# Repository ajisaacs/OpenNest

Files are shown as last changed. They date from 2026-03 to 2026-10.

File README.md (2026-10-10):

# OpenNest

A Windows desktop application for CNC nesting — imports DXF drawings, arranges parts on material plates, and exports layouts as DXF or G-code for cutting.

<p>
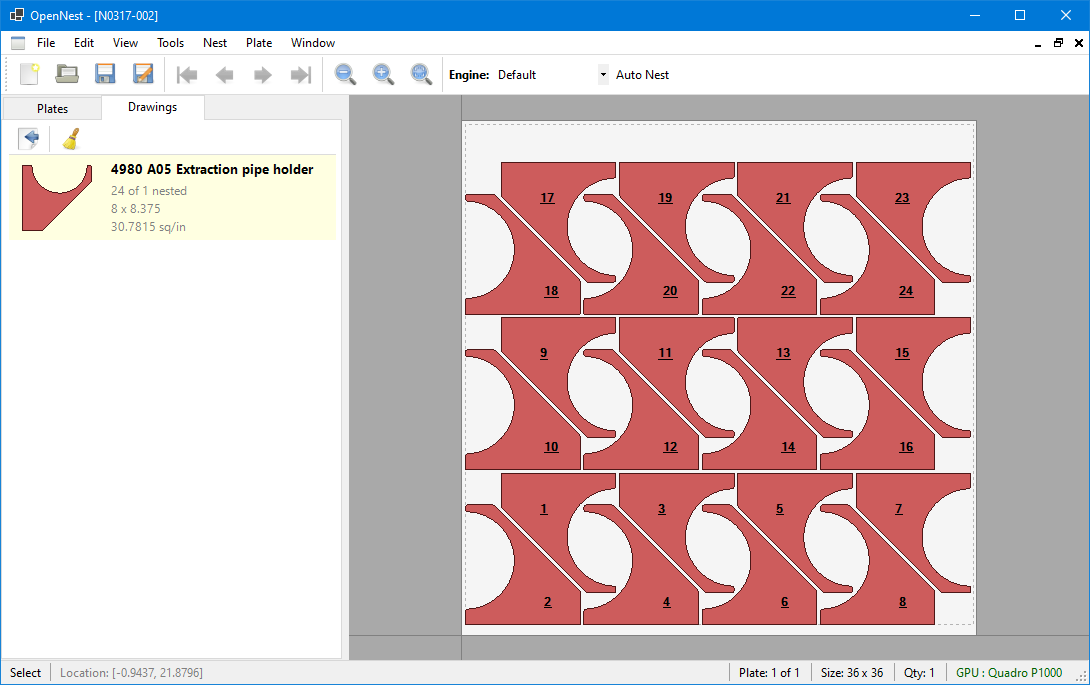
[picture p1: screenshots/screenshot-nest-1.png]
OpenNest - parts nested on a 36x36 plate
  
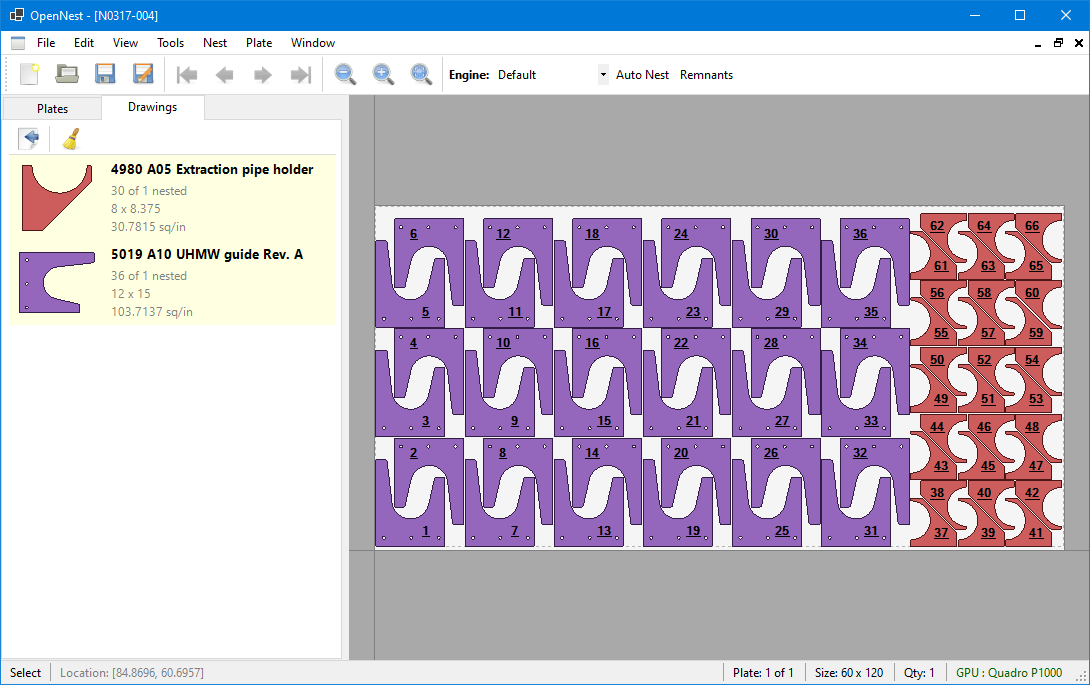
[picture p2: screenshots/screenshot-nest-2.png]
OpenNest - 44 parts nested on a 60x120 plate
  
</p>

## Features

- **Import / export** — DXF & DWG parts (ACadSharp), Excel BOMs, bend-line detection, built-in parametric shapes; export DXF or post-processed G-code.
- **Nesting** — pluggable whole-job engines (Default, Strip, Vertical/Horizontal Remnant, StockLadder, plus DLL plugins), NFP-based interlocking pair evaluation, gravity compaction, rotation sweeps, multi-plate/multi-material jobs.
- **Plate operations** — manual sheet cut-offs, [plate- or nest-wide automatic scrap cutoffs with a minimum tail-to-keep setting](docs/automatic-scrap-cutoffs.md), oversized-part splitting (straight, weld-gap tabs, spike-groove), interactive editing, and spacing-aware pushes that can slide along or away from touching parts.
- **Visual overlap check** — highlight shared material on the active plate, rechecked automatically after edits, including containment and cutouts, with area shading, pair centroids, and hover details through View > Overlap Check. [Usage and limitations](docs/geometry/visual-overlap-check.md).
- **CNC output** — configurable lead-ins/outs and tabs, contour editing, user-defined G-code variables (`$name` → `#200+` machine variables), plugin post-processors (Cincinnati CL-707/800/900/940/CLX included). [Pre-post verification](docs/post-verification.md) checks overlaps, missing lead-ins, and rapid crossings, with explicit risk acknowledgment required to bypass warnings.

## Requirements

- Windows 10+ for the desktop app; the console, API, and most test projects build on Linux/macOS too.
- [.NET 8 SDK](https://dotnet.microsoft.com/download/dotnet/8.0) to build from source.

Windows release ZIPs are self-contained: extract the entire archive into a new folder and run `OpenNest.exe`; no separate .NET installation is needed. The Rectangles and Irregular nesting engines are built in; see [nesting engines](docs/nesting-engines.md). Use the ZIP and SHA-256 checksum from [GitHub Releases](https://github.com/ajisaacs/OpenNest/releases), not the source-code archives.

## Build, Test, Run

```bash
git clone https://github.com/ajisaacs/OpenNest.git
cd OpenNest
dotnet build OpenNest.sln                                       # full solution (Windows)
dotnet test OpenNest.Engine.Tests/OpenNest.Engine.Tests.csproj  # cross-platform engine tests
dotnet test OpenNest.Tests/OpenNest.Tests.csproj                # core/engine/IO/API tests
dotnet test OpenNest.FrontEnd.Tests/OpenNest.FrontEnd.Tests.csproj # console/MCP/API integration
dotnet run --project OpenNest/OpenNest.csproj                   # desktop app (Windows)
```

`OpenNest.WinForms.Tests` (desktop-assembly tests) runs on Windows only; CI runs it and `OpenNest.FrontEnd.Tests` on a GitHub-hosted Windows runner for every master push and pull request. Format changed files with `dotnet format OpenNest.sln --include <path>`.

Shared coding-agent guidance lives in [AGENTS.md](AGENTS.md). [CLAUDE.md](CLAUDE.md) imports it for Claude Code compatibility; make shared instruction changes in AGENTS.md, not in duplicate agent-specific copies.

### Quick start

1. File > New Nest
2. Import DXFs via the CAD Converter (layer/color filtering, bend detection, G-code preview) or create built-in shapes
3. Define plate size, material, quadrant, spacing
4. Fill — the engine arranges parts
5. Optionally add cut-off lines, apply Part Sequencing to order crossing cut-offs before their parts, then save `.nest`, export DXF, or post-process to G-code

Review part spacing before cutting, especially for interlocking pairs. See [pair-spacing checks and current limitations](docs/geometry/pair-spacing.md).

## Command-Line Interface

```bash
dotnet run --project OpenNest.Console -- part.dxf --size 60x120               # fill one plate
dotnet run --project OpenNest.Console -- part1.dxf part2.dxf --size 60x120 --autonest
dotnet run --project OpenNest.Console -- project.zip                          # re-fill a nest file
```

Key options: `--size WxL`, `--autonest` (validated single-sheet whole-job nesting), `--allow-invalid` (explicit warning override), `--engine <name>` (jobs engine or fill strategy), `--quantity`, `--spacing`, `--template <nest>`, `--output <path>`, `--check-overlaps`, `--post <name>`, `--no-save`. Run without arguments for the full list.

## Benchmarking Engines

`OpenNest.Benchmark` runs every registered `INestingEngine` against `.nest` files (or a JSON manifest of DXFs + quantities) and scores by salvage-credited sheet area, with a penalty per unplaced part.

```bash
dotnet run --project OpenNest.Benchmark -- ./benchmark-jobs \
  --sheet-sizes 48x96,60x120,72x120 --engines Irregular,Rectangles --csv results.csv
```

Layouts are validated (bounds, spacing, quantity, rotation, stock match); invalid runs place nothing and pay the penalty. `--parallel` (default 3) speeds up scoring but inflates `Time(ms)` — use `--parallel 1` when comparing speed. Pass `--sheet-sizes` for an unbiased run; otherwise only each file's original sizes are offered. `--progress` logs each solve's start, the engine's `NestJobProgress` (plate evaluations throttled to one line per 2 s, every plate commit) and its finish. Custom engines drop in as DLLs implementing `INestingEngine` (public parameterless constructor) in an `Engines/` folder next to the benchmark. Built-in engines and how to change them: [nesting engines](docs/nesting-engines.md).

## Project Structure

| Project | Purpose |
|---|---|
| **OpenNest** | WinForms desktop app |
| **OpenNest.Core** | Domain model, geometry, CNC primitives; [material-overlap diagnostics](docs/geometry/visual-overlap-check.md) |
| **OpenNest.Engine** | Nesting algorithms and whole-job contracts |
| **OpenNest.IO** | DXF/DWG, `.nest`, G-code, BOM I/O; CAD import |
| **OpenNest.Console** | Headless batch nesting |
| **OpenNest.Api / .Data** | Programmatic pipeline; machine & cutting-parameter data |
| **OpenNest.Gpu** | GPU-accelerated pair evaluation (ILGPU) |
| **OpenNest.Benchmark** | Head-to-head engine comparison |
| **OpenNest.Mcp** | MCP server for AI tool integration |
| **Posts/** | Post-processor plugins (Cincinnati CL / CI Fiber lasers, Gravograph IS8000) |
| **\*.Tests** | Cross-platform suites; WinForms tests are Windows-only |

## Nesting Engines

Engines implement `INestingEngine.Solve(NestJob)`. Desktop Auto Nest, console autonest, MCP autonest and the API use one independent validation pipeline for every engine, including plug-ins. Invalid layouts require an explicit decision; malformed output cannot be kept. See [automatic nesting and validation](docs/automatic-nesting.md) for caller behavior and API validation status.

| Engine | Description |
|---|---|
| **Default** | Any job: runs Irregular and Rectangles and keeps the cheapest valid layout |
| **Rectangles** | Plain and near-rectangular plates: maximal-rectangles box packing |
| **Irregular** | Irregular profiles: no-fit-polygon frontier packing |
| **Fill** | Multi-phase: linear fill → pairs → rect best-fit → extents (named Default in earlier releases) |
| **Strip** | Iterative shrink-fill for mixed-drawing layouts |
| **Vertical / Horizontal Remnant** | Optimizes a clean remnant drop on one edge |
| **StockLadder** | Whole-job, stock-constrained baseline with salvage-credit ranking |

Which engine suits which jobs, renamed engine names, and the rules for changing an engine: [nesting engines](docs/nesting-engines.md).

## File Format

`.nest` files are ZIP archives containing drawing programs, metadata, plates, and placements. Saved nests retain each part's lead-ins, lead-outs, tab gaps, and locks, plus the plate's cutting settings. Changing a drawing's geometry removes obsolete cutting paths from its parts; name, quantity, and color edits preserve them. See the [file-format reference](docs/nest-file-format.md) for compatibility and recovery behavior.

## Supported Formats

| Format | Import | Export |
|---|---|---|
| DXF | Yes | Yes |
| DWG | Yes | No |
| Excel BOM | Yes | No |
| G-code | No | Yes (post-processors) |
| `.nest` | Yes | Yes |

Zoom Out, Zoom In, and Zoom to Fit are centered together with the plate navigation buttons in the plate-view header.

## Keyboard Shortcuts

`Ctrl+F` fill area · `F` zoom to fit · `Shift+wheel` / middle-click rotate · `X`/`Y` push · arrows nudge · `Shift+arrow` push.

## Status & License

Actively developed; core workflows run end-to-end from DXF import to G-code. Contributions welcome. MIT licensed — see [LICENSE](LICENSE).

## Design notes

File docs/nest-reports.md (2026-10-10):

# Nest report PDF export

Desktop: **File -> Export Nest Report...** writes `<nest-name>.report.pdf` for the
active nest's whole job through an overwrite-confirming save dialog. The command
is disabled without an open document and during a background database save, and
it refuses to run while whole-job nesting, an open progress window, interactive
fill or a busy plate action holds the nest or any second window sharing it. After
the dialog closes, the target and those conditions are revalidated; the snapshot
is then captured synchronously on the UI thread and only that detached snapshot
reaches the renderer. Export never changes the selected plate, dirty state,
timestamps or quantities, and it never touches post selection, verification or
CNC output. Opening and printing use any normal PDF viewer; the report includes
no printer controls and there are no persisted report settings or templates.

The same two calls back the command and any future integration:

```csharp
var snapshot = NestReportBuilder.Capture(nest, DateTimeOffset.Now);
NestPdfWriter.Write(snapshot, destinationPath);
```

Reporting does not select a post, generate CNC, refresh drawing quantities, change
the selected plate, or certify that a layout passed geometry/pre-post checks.

## Snapshot contract

- IDs (`1`, `2`, ...) are local to the report. Visit non-cutoff placements in plate
  and part order, then append unseen demanded drawings ordered by ordinal name and
  source path. Identity is by reference: distinct same-named drawings stay distinct,
  including placed drawings absent from the name-keyed drawing collection.
- Recount nested quantities from placements times sheet copies exactly once using
  checked wide integers. Include unplaced demand; report shortage and extra
  separately. Cached `Quantity.Nested` is not authoritative.
- Omit trailing empty stock plates from report pages, layout counts and physical
  sheet totals. Keep the live nest and remaining plate numbers unchanged.
- Distinguish distinct layouts from physical sheets. Per-sheet quantities do not
  include copies; total quantities do. Utilization uses net part area divided by
  full sheet area, excluding cutoffs.
- Actual placed programs already contain rotations. Capture their material paths
  with the location applied once. Preserve holes and intentional tab gaps; exclude
  rapid, scribe, lead-in and lead-out paths. Keep Cut and Display contours.
- If any material contour of a part is open, show all its contours without fill.
  Do not close the gap or substitute the drawing's nominal outline. Cutoffs are
  separate strokes with no product ID or quantity.
- Snapshots retain values, not live drawings, parts, CNC programs or mutable
  geometry. Invalid/missing/nonfinite geometry fails with drawing/plate context.

## Layout, pagination and dense-label fallback

An empty/demand-only job, a single plate, or many plates and drawings all
produce one document: a Letter portrait summary followed by one Letter
landscape section per plate, every page carrying a repeated header and
"Page X of Y". Long notes, long drawing names, many drawings and many parts
per sheet paginate naturally: MigraDoc continues the Plates/Parts tables and
each plate's part table across pages with the heading row repeated, and notes
flow as an ordinary paragraph. No row, table or note text is ever dropped or
truncated to fit a page.

Stock sizes read **width x length** in job units. Plate tables use **Quantity**
and **Parts per plate**; the plate quantity multiplies per-plate part counts for
the totals.

Individual IDs use 7 pt text centered on the part's pole of inaccessibility
(`PolyLabel`, as in `PlateView`), clear of edges, holes, cutoffs and other labels.
The search uses a placement-independent quantized copy for consistent placement
on identical parts. Labels are best effort: there are no closeup or grid pages,
and a part too small to label never prevents export. Every part remains in the
quantity tables even when its diagram label cannot fit.

Nearby small parts with the same report ID may share a dotted rectangular outline
and one ID beside it. Separate clusters get separate outlines. A group is omitted
if its rectangle includes any other part or cutoff, or if there is no clear space
for its label. Dotted group outlines are distinct from dashed scrap cutoffs.

The writer still rejects, with `NotSupportedException` and before touching
the destination:

- a page header (nest name plus plate/material line) needing more than 3
  wrapped lines;
- a table cell needing more than 20 wrapped lines.

Summary thumbnails and the sheet diagram are vector paths, never raster images.
Each thumbnail is a small PDFsharp page embedded by MigraDoc as a form XObject.
The diagram is drawn into a fixed-height table row reserved in MigraDoc's flow,
located after layout with `DocumentRenderer.GetRenderInfoFromPage`. Closed parts
use one even-odd filled path, so holes stay unfilled. Parts with any open contour,
and cutoffs (dashed), stroke each contour as its own path: PDFsharp's
`StartFigure` does not start a new subpath after an open figure, and would
otherwise draw a false segment across a tab gap.

A report is fully rendered to a unique temporary sibling before replacement of
its destination. A failed render or write leaves an existing report untouched and
removes temporary output. Applications should obtain overwrite consent before
calling the library. PDFsharp/MigraDoc layout and font state is process-wide;
`NestPdfWriter.Write` serializes every export behind one static lock so
concurrent calls cannot lay out text differently from a sequential export.

Advanced timing, cutting distances, pierce counts, weights, costs, gas use, and
machine/NC identity are intentionally omitted until their semantics are verified.
The PDF can be opened or printed through a normal PDF viewer; its fitted diagram
is not a dimensioned cutting drawing.

## Backend, fonts and redistribution

- Official `PDFsharp-MigraDoc` Core **6.2.4**, with `PDFsharp` **6.2.4**, targeting
  net8.0. No GDI/WPF dependency or printer driver is used. MigraDoc owns flowing
  document layout; PDFsharp draws vectors into its measured reserved areas.
- DejaVu Sans **2.37**, regular and bold, is bundled unmodified as assembly
  resources. Source: https://dejavu-fonts.github.io/ ; binary provenance:
  Ubuntu `fonts-dejavu-core` **2.37-8**. Both required faces are embedded in PDFs;
  neither generation nor viewing needs a platform font installation.
- A custom resolver is installed once before fonts are created. Repeated exports
  reuse it. An already-installed foreign resolver is an explicit integration
  error, never silently replaced. A host that already uses PDFsharp needs resolver
  composition before adding report support. MigraDoc's predefined error font is
  pointed at the bundled family; its default (`Courier New`) is a platform font
  the bundled resolver deliberately cannot supply.
- The initial text contract is printable ASCII/Latin-1 and line/tab separators.
  Other codepoints, controls and soft hyphens fail with the field and codepoint;
  there is no silent missing-glyph substitution. Broader Unicode/shaping support
  is deferred rather than implied by the font's larger character inventory.
- PDFsharp/MigraDoc are MIT-licensed. The actual v6.2.4 license and the Microsoft
  transitive dependency notices are in `OpenNest.Reporting/THIRD-PARTY-NOTICES.txt`.
  Font permission/redistribution terms are in `OpenNest.Reporting/Fonts/LICENSE.txt`
  (Bitstream Vera permission with DejaVu changes in the public domain). Preserve
  both files in `ReportingNotices/` when publishing; embedded fonts do not replace
  the obligation to ship their notices. Package notices are deduplicated, not
  rewritten or shortened.

## Verification

```sh
dotnet test OpenNest.Tests/OpenNest.Tests.csproj --filter FullyQualifiedName~Reporting
```

The writer tests read page sizes and content streams with PDFsharp. Text
assertions use Poppler's `pdftotext -bbox` coordinates to rebuild visual rows;
`-layout` can return columns in a different order on Windows. They are skipped,
not passed, when poppler-utils is absent. The Windows release workflow installs
an SHA-256-pinned Poppler binary because the runner's built-in `pdftotext` lacks
`-bbox`; no PDF text test is skipped for that reason in a release candidate.
For manual inspection also use `pdfinfo`,
`pdffonts` and `pdftoppm -png` (Linux verification baseline: poppler-utils
24.02.0). Confirm page sizes, quantity rows, page X of Y, embedded fonts, native
vector curves, unfilled holes and visible tab gaps with no connecting stroke.
Pixel inspection supplements geometry assertions; it is not a CNC-validation
result.

Windows compilation is not runtime acceptance. `OpenNest.WinForms.Tests/Forms/NestReportExportTests.cs`
covers enablement, busy/cancel/failure/success adapter behavior, but it only
compiles on Linux. Windows runtime acceptance still owes: exporting a real nest
(and the packaged application, so bundled fonts/notices are verified), checking
page sizes/labels/copies and embedded fonts with `pdffonts`, a tabbed part with a
hole, opening and printing the PDF, and exercising fill/nesting rejection, cancel,
overwrite and invalid-path behavior with job state and any existing destination
unchanged.

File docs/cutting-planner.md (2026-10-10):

# Unified cutting planner: direct-XY proposals

`OpenNest.Engine.CuttingPlanning.CuttingPlanService` plans contiguous whole-part
programs. It can retain fixed programs or jointly choose internal contour order,
entries and whole-part order using explicitly confirmed cutting parameters. It
returns an owned proposal; `Apply` installs Ready plate-scoped proposals atomically
after an exact freshness check. The desktop opens it from `Plate > Plan Cutting...` and
`Nest > Plan Cutting (All Plates)...` (see [Desktop workflow](#desktop-workflow)); the older
automatic sequencing and lead-in assignment commands remain until they are retired.

## Capture before worker planning

Create a `CuttingPlanRequest`, then call `Capture` while source placements,
programs and settings are stable. Pass that snapshot to `Plan` on a worker;
`Plan(request)` combines these steps synchronously. The modeled starting point
defaults to `Vector.Zero`, not a discovered controller position.

```csharp
var request = CuttingPlanRequest.ForPlate(plate, startPoint: start,
    confirmedParameters: parameters, expansionBudget: 20000,
    maxEntries: 16, preservePartOrder: false);
var snapshot = CuttingPlanService.Capture(request, cancellationToken);
var result = CuttingPlanService.Plan(snapshot, cancellationToken);
```

- A plate-scoped request (`CuttingPlanRequest.ForPlate`) plans the plate's current
  parts and records its exact state for `Apply`. A detached part list (`new CuttingPlanRequest(parts, ...)`)
  plans the same way but can never be applied. An empty plate is a Ready no-op.
- Omitting `confirmedParameters` preserves the original fixed-program contract:
  locked and unlocked programs stay fixed; only whole-part order may change.
- Supplying confirmed parameters enables regeneration for unlocked placements.
  `eligibleParts` can restrict it to an explicit reference-based subset; an empty
  subset retains all programs but still checks their leads against owned material.
  Locked placements never regenerate. Foreign or duplicate eligible identities
  are invalid; eligibility without confirmed parameters is invalid.
- `preservePartOrder` fixes whole-part order, not eligible internal contour choices.
- Parameters are caller-confirmed inputs. The service does not recover missing
  operator settings or silently change lead styles to find a solution.

Capture owns clean geometry, placed programs and required settings. Source `Part`
references are identity handles only: workers never read their mutable state.
Clean geometry accounts for the base program's existing rotation before applying
placement rotation; placement translation is applied once. Subprogram copying
must not rotate shared programs through their property setters. No live drawings
are attached to preview plates, so capture/search do not change quantity accounting.
Planning works from this historical snapshot; Apply compares it with live state.
Original
clean and executable graphs are type/mode-checked before cloning can erase unknown
semantics. Exact placed/proposed copies preserve authored motion feed/exact-stop
flags, symbolic bindings and shared subprogram identity; unsupported graphs are
refused. The geometry-only clean transform uses per-parent copies so legacy rotation
does not visit a globally shared descendant twice; it never changes the fixed payload.

## Cutting dependencies

Nominal material validation recognizes contacts at shared endpoints of adjacent
contour segments using `OpenNest.Math.Tolerance.Epsilon` (0.00001 model units).
This avoids false self-intersection warnings from rounding at arc/line joints,
including the contour seam. Overlapping segments and contacts away from those
joints or between separate contours still fail validation. For adjacent finite arcs
with a shared endpoint, material validation filters native contacts against both
actual arc spans: the native query's angular padding can otherwise report a
supporting-circle intersection beyond one arc's endpoint. This does not increase
the joint-distance tolerance, discard overlapping arcs, or waive a second intersection
inside both spans. Lead and rapid checks keep their conservative contact queries.
Source contour closure
in material capture and emitter preparation accepts endpoint gaps up to 0.000001
model units (inches for an inch nest), with a floating-point roundoff allowance
capped at 1e-12. It does not rewrite source endpoints. Native intersections,
executed-motion checks and pre-post verification retain their existing tolerances.

Capture builds whole-part prerequisites from owned values, and both the search and
the final replay enforce them:

- A cutoff precedes every part its nominal line crosses within its span, using the
  same rule as automatic sequencing: nominal position and limits against the part's
  placed bounds, matched by drawing reference, never by name or trimmed segments. A
  cutoff whose definition is missing precedes every part. Cutoffs need a
  plate-scoped request; they are always fixed programs, need no lead-in, are not
  material for lead validation and, being open cuts, never become rapid obstacles.
  Rapids into and out of them are still checked.
- A part whose perimeter lies strictly inside a cutout of another part precedes
  that host. Material bounds (never rapids or scribe marks) only select candidate
  pairs; containment is proven on native clean material. Touching or crossing boundaries, or material that cannot be
  captured, refuse as `UnsupportedGeometry` naming both parts. A part in a concave
  pocket outside the host's material has no dependency.
- A preserved manual order that violates a prerequisite, or a cycle, is a
  `ConstraintConflict`. Replay rechecks the captured prerequisites and refuses a
  violating order rather than trusting the search.

## Search and exact output

With regeneration, the bounded deterministic search plans internal contour order
and native entry candidates part by part along a whole-part order. Internal
contours precede their own perimeter; parts remain contiguous. Backtracking can
revisit an earlier entry when a later part cannot be reached safely. For multi-part
requests containing regenerated holes, it first tries one ranked hole chain for
each outside endpoint. This lets a later blocked approach change the previous
part's departure without first exhausting combinations of its earlier holes.
This preferred pass uses the same emitted-motion checks, shared expansion budget
and stall limit as the retained search; on failure the full entry/hole-order
backtracking pass remains available. Single-part and no-hole requests keep their
existing search order.

A preserved order is followed as given. Otherwise the order is an open
travelling-salesman path over part centres from the start point: nearest neighbour,
then 2-opt reversals and Or-opt moves of one to three parts, never placing a part
before a cutoff or nested-part prerequisite. If a part on that order cannot be
reached without crossing parts already cut, the search learns "cut this part
before those", backs up to just before the earliest of them and re-plans the rest
from the tool position there; parts cut before that point are kept. An attempt
stops backtracking after a stall of 8 x entries x contours expansions without
getting further, so it learns instead of retrying every entry combination of the
parts before it. A rule that would contradict an order already required is skipped.
"Cut before" rules are a heuristic (a part blocked straight after another may be
reachable via a third), so once nothing new can be learned the remaining budget
goes to a full search that tries every ready part, nearest first; only when that
also fails is the result a refusal.

Candidates use native closest points, vertices, midpoints and circle angles in
stable order, capped by `maxEntries`. Circle rounding, clamping, corner resolution
and tab trimming happen during emission. Validation uses the actual emitted
motions, never the nominal entry point alone. Existing lead styles are not
shortened, disabled or substituted as a search fallback.

Whole-circle candidates rank by distance to their next-cut target; for a hole,
that is the next contour's actual pierce. They do not reward a diagonal point as
if it were a bounding-box corner. All eight
compass options remain available, including the four polar points at 0°, 90°,
180° and 270°, and every alternative still passes the emitted-lead and rapid checks.
Without a next-cut target, the arrival-based rule is unchanged. Polygon corner
preferences are unchanged.

`Round Lead-In Angles` remains an explicit cutting setting: a 90° increment snaps
circular-hole starts to the four polar directions; 45° also permits diagonals.
Snapping can increase reuse of identical hole subprograms and reduce output for
posts that support that reuse, at the cost of a less direct departure. It is not
a clearance exemption or a guaranteed file-size reduction. The planner does not
silently enable rounding, change the increment, or bypass checks on the rounded
motions.

Every candidate rapid is checked against contours already completed, including
earlier holes in the same part. Future contours are not yet obstacles. Rapid
checks skip completed contours whose extents are more than 0.001 clear of the
rapid, ten times the widest band any native contact query allows beyond an
extent; anything closer, touching included, gets the full native check. Lead
checks examine every other part's material: native line/circle queries can report
rounding contacts for long leads far from small circles, and leads keep those
results. An arc's
extent is its whole supporting circle widened to the distance at which the native
contact query still counts it as touched (for a very small arc up to 0.0001 beyond
its radius). Nothing is skipped when either extent has a nonfinite bound or reaches
beyond 1e6, where rounding of large supports can exceed any fixed margin. Actual
lead-in and lead-out line/arc paths must stay in target scrap and avoid other
placed material; holes in other parts remain scrap. Tangent/coincident contacts
outside the genuine target contour joint and numerically uncertain queries refuse.
Material capture supports a simple closed perimeter minus disjoint, non-nested
holes; unsupported topology is not a bounding-box approximation. A line meeting a
tangent arc at a shared vertex, such as a fillet, is an ordinary joint: an exact
contact that the native query rounds away is not uncertain at a line endpoint the
other curve already touches, while a contact anywhere else on the line still refuses.

Source parts rank by modeled travel (material-centre distance at a holed-part
boundary); within a part, preferred contour order and facing-entry rank precede
travel. Ties use stable source/contour/entry ordinals. Hash values and drawing names
are not tie breakers.

When the next whole part is fixed by the tour or a part is already active, the
search generates and checks contour alternatives on demand in contour/entry rank
order. It does not emit every sibling before trying the first. Backtracking still
visits the remaining alternatives when needed; none is pruned. The free whole-part
fallback still evaluates all ready sources before ranking their travel distances.

The expansion budget counts evaluated candidates and frontier ranking, including
rejections, before emission; it is not a wall-clock timeout. An unvisited sibling
consumes no additional DFS-prefix emission work or per-sibling expansion charge;
entry-catalogue prechecks still emit isolated contours and consume budget.
Consequently a bounded search can
reach a different frontier and report different rejected approaches than eager
expansion did. All visited candidates retain their lead/rapid checks, and a selected
plan still receives fresh independent replay. Callers can cancel. Exhaustion returns
a refusal, not an unranked fallback or proof of geometric impossibility.

## Automatic outside entries and look-ahead

An unlocked part's outside entry is chosen automatically toward the NEXT cut: the ranker orders the native candidate
catalogue by the facing side(s) of the next part's placed-material centre, and
the shared lead validator certifies each emitted lead lazily until up to
`maxEntries` feasible candidates remain. At caps of four or more, a corrective
scan reconsiders memoized clear candidates for each missing side before evaluating
more of the catalogue; a later side cannot lose a usable point merely because
an earlier side's scan passed it. Replacements preserve other covered sides and
global rank, never exceed the cap, and stop evaluating the tail once coverage
settles. Smaller caps retain rank priority rather than promising all-side coverage.
The next cut is the next unfinished part in a supplied order — recomputed
after every learned-order replan — or, in the full fallback search, the nearest
dependency-ready remaining part, stable-ordinal ties; the last part has no
target and ranks by tier then distance to the tool's arrival. Between source
parts the tour stays nearest-first; the look-ahead rank only orders the entries
inside one part's contour stage, so distance sorting cannot undo the facing.
Uncertain (numerically incomplete) validator answers are not geometric refusals:
those candidates can fill remaining retained slots for emitted-prefix checking and
complete replay. The total retained entry count stays within `maxEntries`. A
part/contour with no fitting lead in its fully evaluated catalogue is reported
as "No tested lead-in fits on part N, contour M"; budget exhaustion stays a
budget finding and incomplete checks are never presented as geometric
impossibility. Lead prechecks are reported separately and their requests also consume
the shared expansion budget before native work.

For a holed part, the search chooses an outside endpoint before cutting any hole.
Each endpoint branch builds an open hole-centre route from the original arrival to
that endpoint, using bounded nearest-neighbour, 2-opt and Or-opt improvement.
Preferred hole entries are then resolved backward from the outside's actual emitted
pierce, ignoring scribe marks: each hole faces the following contour's actual pierce.
Convex corners lead the preference tiers, then straight midpoints/tangent joints,
then native fallbacks. Reflex/cusp corners remain manual-only.

This preference orders the search; it never certifies a rapid or prunes alternate
retained entries or hole orders. A different outside endpoint recomputes its hole
preference. Every standalone emitted prefix is replayed from the original part
arrival and a copy of the checker from before that part, not from the previous
prefix (which would double-consume holes and scribes). Holes are cut once, the
outside last, and scribes once. Locked programs remain exact. A crossed preferred
route must recover through checked backtracking or return a refusal, never unsafe
`Ready`.

Selected programs are replayed from the beginning with a fresh checker and fresh
lead validation, without regenerating them or trusting cached search verdicts.
Before replay, expected-emission geometry is independently built from the owned
choices/settings, not from the candidate payload. Replay checks actual selected
code against it and independently accounts for directed native boundary coverage:
no partial, duplicated, retraced or reversed cuts, except the exact selected tab.
Equivalent subdivisions and merged collinear moves remain valid. Captured source
identity and pose binding use exact scalar bits, not geometric tolerance.
Arrival positions use actual departures, including lead-outs and subprograms.
`ProposedOrder` retains source identities/poses; `CopyProgram()` returns an
independent deep copy of each exact captured/generated program. `ContourChoices`
are nominal choice metadata, not a substitute for reading actual execution.
Neither obtaining a proposal nor copying its programs installs them on live parts.

## Results and refusal

`Ready` and `IndependentlyReplayed` describe the modeled proposal only. In the
no-parameter fixed route, replay checks rapid crossings and
incomplete retention; it does not add regeneration-mode material/lead checks.
In regeneration mode, replay also checks actual lead paths and contour accounting
against owned clean material. Neither mode certifies final NC, production cutting
readiness or physical machine safety.

Findings and source ordinals use the original zero-based source list, not proposed
sequence positions. Strict service refusals contain no proposed order. The desktop batch may
produce a separate `BestEffort` proposal as described below; it never labels it `Ready` or
sets `IndependentlyReplayed`.

- `ConstraintConflict`: fixed programs or explored fixed routing violate the
  modeled constraints. Locked internal crossings cannot be repaired by regeneration.
- `UnsupportedGeometry`: unsupported motion/material semantics or an incomplete
  check. Open nominal outlines, ambiguous release states or containment, cutoffs
  in a detached part list and scribe-only source drawings are not silently accepted.
- `InvalidInput`: malformed/missing/duplicate placements or settings, invalid
  geometry, empty input, invalid eligibility or nonpositive bounds.
- `NoSolutionWithinBudget`: the bounded/capped search found no complete proposal;
  it does not prove no possible geometric route exists.
- `Cancelled`: capture, search or replay cancelled without live mutation.

Malformed original executed graphs are refused, not salvaged. Valid but incomplete
old programs can regenerate from clean geometry. Regenerated programs retain genuine
configured tab gaps; stale tab settings do not establish retention. In confirmed-
parameters mode, locked/ineligible programs must cover the complete directed clean
boundary: an open fixed program has no certified selected tab metadata and is refused,
not repaired, even if it may have been intentionally tabbed. The no-parameter route
retains its narrower compatibility contract. A lead-out that may bridge a tab, or
a malformed emitted arc, is refused, not automatically repaired. Tabbed lead-outs
leave from the trimmed cut end, but a lead-out after an open contour still needs
manual review of its retention gap, so confirmed-parameters planning refuses it.

## Apply

```csharp
var commit = CuttingPlanService.Apply(results, cancellationToken); // one result per plate
```

Call it on the thread that owns the plates, with Ready, independently replayed
results from plate-scoped requests; anything else is `InvalidInput`. Apply never
replans. Each plate is compared exactly with the state captured with its request:
part list instance and order, plate quantity/size/quadrant and settings, cutoff
definitions, and for every part its program reference and exact content (an
in-place edit counts), drawing program and cutoff classification, pose bits,
lead-in/lock flags, settings (reference and exact content) and bounds. Any
difference on any plate returns `Stale` and changes nothing, so a proposal that
changes a plate can be applied once; an unchanged (no-op) proposal stays current.
A malformed live program is also `Stale`, not an exception. A part repeated on
two plates of one scope is `InvalidInput`. Caller-confirmed planning settings are
input, not plate state: editing a separate confirmed-settings object after
capture does not stale the result (confirmed settings that are also a part's or
the plate's live settings are live state, and editing them does). Settings are
compared member by member, and only the exact built-in settings types are
supported (the same set regeneration copies): a plate-scoped request whose part
or plate settings, or any lead-in, lead-out, tab, sequencing or assignment
object inside them, is another type (a subclass included) returns
`UnsupportedGeometry` without running that type's code. A settings object
replaced by such a type after capture makes `Apply` return `Stale`. Detached
part-list requests do not capture settings and are unaffected.

The whole scope is validated and its bounds staged first; cancellation is checked
immediately before the install. Order changes through `ObservableList.Reorder`
semantics: same references, no `PartAdded`/`PartRemoved`, so drawing quantities,
sentinel plates and plate lists are untouched. Regenerated parts receive a fresh
owned copy of the replayed program and of the settings captured with the request,
keep their pose and lock, and are marked as having lead-ins. Fixed programs are
not replaced. An exception during install restores every plate exactly and returns
`Failed`. The installer itself is internal: it trusts these owned payloads and
checks only root program references, so `CuttingPlanService.Apply` is the only
public path. After the whole scope is installed, each changed plate raises
`Plate.PartsReordered` once; an observer exception is reported in `RefreshErrors`
on an `Applied` result, not as a rollback.

## Desktop workflow

`Plate > Plan Cutting...` plans the active plate and `Nest > Plan Cutting (All Plates)...`
plans every plate that has parts. Both open one dialog built on
`OpenNest.Engine.CuttingPlanning.CuttingPlanBatch`:

- The dialog starts from the plate's cutting settings (or the last-used settings) and plans
  at once. `Cutting Settings...` edits them and `Keep the current part order` fixes the
  whole-part order; either change replans. The settings are confirmed parameters: every
  unlocked part's lead-ins are regenerated. Locked parts keep their exact programs;
  the strict route checks them, while any best-effort warnings require explicit review below.
- Lead-ins are optional for planning. With `None` (or a style that emits no lead
  motion), the emitter places the pierce directly on the selected contour point.
  Unlocked contour starts can still move to improve travel; locked programs keep
  their existing starts. Search and independent replay still check rapid crossings,
  emitted lead paths when present, and contour accounting. The separate pre-post
  missing-lead warning remains available for operator review; a ready plan does not
  waive posting checks.
  When a lead hits another part, the finding suggests more spacing or a shorter lead;
  when no tested entry fits, it suggests reducing lead-in length and, if neighbours
  obstruct it, spacing the parts farther apart. These are suggestions, not guaranteed
  fixes: replanning runs the same strict checks; an unverified fallback requires
  separate warning acceptance and is not approval to post or cut.
- The desktop free-order batch first tries up to eight entries per contour for at most
  1,000 expansions. Only a Ready proposal that passes independent replay is used;
  otherwise it runs the original 16-entry search with its entire plate budget.
  Cancellation stops both attempts. This short pass can choose a different valid
  route, and a hard plate can take up to 1,000 extra expansions before the full
  attempt. The current-order retry still uses its original 16-entry budget.
  Returned expansion counts describe the retained attempt, not a discarded
  short pass plus its full-cap retry.
- Every plate is captured on the UI thread and checked and planned on a worker. Clean part
  material is checked for overlaps with the pre-post overlap analyzer; known overlapping parts
  still block that plate whatever its route. Incomplete checks remain visible warnings, never
  a clear result (see [pre-post verification](post-verification.md)). A free-order search that ends
  `NoSolutionWithinBudget` is retried once with the current part order, and the summary
  says the order was kept. Both are allowed 400 expansions per part (at least the
  default 20000), because both still plan contour order and entries for every part.
- The dialog uses an owner-monitor-sized window (approximately 90% of the working area), like
  the database browser. The right panel keeps the batch outcome and plate headings above a
  read-only, unsorted warning grid with Plate, source Part, With, and full finding text. Every
  overlap issue/pair and every planner finding has its own selectable row, including findings
  hidden by the compact blocked-plate summary. Selecting a row switches to that plate's
  detached preview and zooms to the affected part extent (or both parts for a pair), mapping
  source positions to the proposed cutting order. This is not an exact contact marker: most
  findings do not carry a geometric witness. If a plate cannot produce a current, supported
  preview, no geometry is cloned or focused; the row still identifies its source part in the
  editor. Replanning, cancellation and stale Apply clear old warning targets.
- The summary lists every plate: ready plates with part counts and rapid travel, others
  with their status and findings. Unverified proposals retain every overlap and route
  warning in the selectable grid before the acceptance checkbox is used; they do
  not truncate later parts' warnings. Finding part numbers are the plate's current order, as the
  editor numbers them. The preview shows the active plate detached from the nest (quantity
  zero, so drawing quantities do not change) in the proposed order with the proposed
  programs. Ready and best-effort proposals can be previewed only while the plate still
  matches capture. Best-effort previews are labelled `UNVERIFIED`. Refused program graphs
  are never copied, and changed plates require replanning.
- Apply requires usable output for every plate and remains all or nothing. The summary
  counts best-effort proposals as usable when reporting how many plates block Apply;
  their warnings still require acceptance. Open nominal contour findings identify the
  contour number, endpoint gap in model units (the nest's linear units), and closure
  tolerance, so the source can be reviewed in the drawing editor. Reporting never
  closes gaps or changes the validation tolerance. A fully ready batch
  can apply immediately; an unverified batch requires the unchecked, per-proposal
  `I reviewed the warnings. Apply this unverified plan.` checkbox. Replanning clears it.
  Both use the same owned-program, freshness and rollback boundary. After it applies, each plate keeps its own copy of the
  confirmed settings, which also become the saved defaults. `Stale` keeps the dialog open
  and asks for a replan; nothing changes.
- Closing or cancelling while planning cancels the worker and keeps the dialog open until
  it stops. Planning and Apply refuse to start while a nesting or plate operation runs.
  The dialog plans with its own copy of the settings, and posts progress and results to
  the thread it was created on rather than to whichever context is current.
- `PlateView` follows `Plate.PartsReordered`: it redraws parts in the plate's order (the
  numbers it draws are the cutting order), rebuilds their graphics and marks the overlap
  check out of date. Both the editor and preview build outlines and lead paths in the
  drawing-local frame, then apply the part placement once. Absolute (G90) programs
  therefore follow moves and clones just like incremental (G91) programs; displaying a
  part does not rewrite its program or coordinate mode.

### Best-effort fallback for imperfect geometry

When strict planning reports unsupported or incomplete geometry, the desktop batch
automatically attempts a bounded, deterministic best-effort proposal. Touching, intersecting
or numerically uncertain material boundaries need not prevent lead-in generation when their
closed executable contours are readable. The fallback reuses the existing contour emitter:
internal contours first, the largest bounding perimeter last, nearest entry from the preceding
departure, with the confirmed lead styles. It retains source part order except to satisfy
proven cutoff and nested-part prerequisites. `Keep the current part order` still refuses an
order that contradicts a proven prerequisite. Uncertain containment is named as a warning.

No source contours are repaired, removed, simplified, or silently closed. Locked programs
and cutoffs remain exact. Unknown/null/recursive instruction graphs, suppressed or nonfinite
motions and contours the emitter cannot represent still refuse. This fallback is for
incomplete geometry checks, not every constraint conflict or exhausted search. Known
inter-part material overlap still blocks the entire batch.

The result retains strict refusal findings and available rapid-check findings, and is
explicitly not a certificate of lead clearance, rapid travel or material containment.
Inspect the preview and warnings before accepting it. A route with only an incomplete
overlap check may likewise be accepted with warnings. `CanApply` and parameterless batch
`Apply()` remain strict; `CanApplyWithWarnings` and `Apply(acceptWarnings: true)` are the
explicit review path. `CuttingPlanService.Apply` still rejects best-effort results directly.
Acceptance never skips the separate pre-post checks or grants posting consent.

## Remaining integration boundaries

The service does not establish clean-material non-overlap, scrap release by open
cutoff cuts or sheet edges, or physical retention strength. It does not write CNC
or set posting consent. A `Ready` proposal can still be unsuitable for cutting.

Later slices route the lead-in side panel's automatic assignment through the planner
and retire the legacy automatic paths. Windows interaction,
supplied-job coverage and actual posted order remain separate acceptance gates.
Fresh [pre-post verification](post-verification.md) is still required; it is not a
physical safety qualification.

## Portable regression gate

```sh
dotnet test OpenNest.Tests/OpenNest.Tests.csproj -c Release --filter 'FullyQualifiedName~CuttingPlanning|FullyQualifiedName~PostVerificationAnalyzerTests'
```

Synthetic fixtures exercise whole-part routing and internal-hole crossing repair,
locked/ineligible refusal, actual native lead paths, shared subprograms, ownership,
entry/whole-part backtracking, deterministic budgets, cancellation and fresh replay
rejection. Retained emission characterizations cover styles, winding, corner rules,
circle rounding/clamping and tabs; unsupported cases remain explicit refusals.

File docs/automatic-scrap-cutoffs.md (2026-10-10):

# Automatic scrap cutoffs

Finish nesting, then choose **Nest > Automatic Scrap Cutoffs (All Plates)** to process the entire nest with one dialog. **Plate > Automatic Scrap Cutoffs** still processes only the active plate. The manual **Sheet Cut-Off** command remains available.

## Preview and apply

1. Finish or cancel any active nesting/fill operation first, and wait for it to finish stopping; closing its progress window alone does not finish the operation. Enter strip spacing along the sheet's length. The initial value is **35 in**, or **889 mm** for a metric nest. This is the distance between nominal cut lines, not the length of a cut.
2. Set **Minimum tail to keep**, initially **12 in** or **304.8 mm**. This measures the reusable tail's length along X, after separator clearance, not its area. A shorter tail does not get a new final separator; a tail at or above the minimum can be retained. Zero allows any positive tail.
3. Opening the modal dialog previews the initial proposal. After changing either setting, choose **Preview** to refresh it. Cuts run across the active sheet's actual width, advancing along X from the origin-side edge in the plate's quadrant. Review the used span, proposed separator, retained tail dimensions, and diagnostics; the sheet cannot be edited while the dialog is open.
4. Choose **Apply** (or **Apply to All Plates**) to recalculate against the current parts/settings and add ordinary cutoff definitions at the end of each plate's cutting sequence. Blocked or empty proposals add nothing. Existing parts and manual cutoff definitions are not moved or reordered. **Cancel**, Escape, and closing the dialog discard the detached preview.

For the Nest command, the on-sheet overlay and upper measurements show the active plate; the scrollable diagnostics list reports every plate's proposed cuts, occupied/used spans, retained tail and warnings. Each plate uses its own dimensions, quadrant and part spacing with the dialog's common spacing/minimum-tail settings and current cutoff clearance/direction settings. No plate navigation or per-plate confirmation is required. Empty or unchanged plates are left untouched. A blocking conflict or invalid plate prevents changes to **all** plates, with the plate number reported; resolve it before retrying. If application fails after changes begin, all touched plates' original cutoff programs and sequence are restored. An explicit incomplete-recovery warning requires manual review before saving or cutting.

An empty sheet is left untouched. Invalid input or out-of-sheet part geometry prevents automatic planning. Excessively small spacing is rejected rather than allocating an unbounded number of cuts. Ordinary floating-point roundoff between translated material and cached bounds is accepted without changing the part or its program; cutoff obstacle checks and fallback exclusions receive the same conservative numerical padding. Larger discrepancies (for example, an inconsistent arc center corrected during conversion) still prevent planning rather than risking a cut through material; repair the geometry before retrying.

## Preserving the unused tail

A proposed tail shorter than **Minimum tail to keep** is left attached to the scrap skeleton by omitting only the final separator. The nominal skeleton grid is not extended into that tail, and no retained tail is claimed. Existing cutoff definitions—including an end cutoff from an earlier run—are never removed by this setting.

Only real parts contribute to the occupied envelope; existing cutoff parts do not. When there is room, the final separator is beyond the furthest occupied extent by the larger of plate part spacing and cutoff part clearance, plus numerical tolerance. Repeated skeleton cuts stop before that separator. The larger margin affects only the separator: repeated cuts keep the existing manual-cutoff clearance behavior.

Cutoff trimming measures clearance from the part contour, excluding tagged lead-in and lead-out moves when building the closed outline. Leads must not turn a recessed outline into a convex hull and leave oversized gaps elsewhere. Genuinely open contours still use the conservative hull/bounds fallback. The conservative curve/offset approximation can leave a small extra gap (about 0.0003 in on a straight edge at the default 0.02-in clearance), not an extra quarter inch.

If no safe separator fits inside the sheet, there is no retained-tail claim and the nominal cuts may cover the full sheet length. A proposed tail is not reported as separated unless its generated program spans the full sheet width. Obstructed or minimum-length-filtered lines produce diagnostics; they are not proof of a completed partition.

For a 120-by-81-inch sheet whose parts extend through 80 inches, the nominal skeleton lines are at 35 and 70 inches, followed by a separator beyond 80 inches at the required margin. There is no line at 105 inches through the retained tail.

## Limits and operator review

**View > Draw Rapids** follows the complete cutting sequence: an incoming rapid ends at a cutoff's first pierce, gaps between its trimmed segments remain rapids, and the next part's rapid starts at the cutoff's final cutting endpoint—not its last pierce. This display does not add a return move or alter the cutoff program.

- Spacing is nominal. Clearance gaps and suppressed short segments can leave bridges between scrap regions. This command does **not** certify that every connected scrap piece is disconnected or fits a hopper.
- The active sheet's physical width is used, not a hard-coded 81 inches. Check the actual width against the hopper; a wider sheet is not automatically hopper-compatible.
- Internal-hole scrap is not processed. This command reuses the outside-skeleton behavior of manual cutoffs; it does not force cuts through parts or remove clearance to guarantee separation.
- Review the preview and posted NC using the normal machine-review process before production cutting.

## Part sequencing

For **Plate > Sequence Parts > Manual Sequence**, choose the one-based sequence number and hover a part on the sheet; only the part under the pointer is outlined. Click it to place it at that exact position, then the number advances up to the last part. Clicking empty sheet space changes nothing. Use **Done**, the window close button, right-click on the sheet, or Escape to leave the tool. Manual reordering changes neither geometry nor quantities.

After adding cutoffs, apply **Part Sequencing** to the current plate or all plates. Each cutoff is moved earlier as needed so it is cut before every part its nominal line passes through. Ordinary parts retain their relative order from the chosen sequencing route; a tail separator that crosses no parts keeps its normal route position rather than being forced to the front. Cutoff geometry, clearance, part programs, placements, and quantities are unchanged.

The dependency check uses the nominal horizontal/vertical line and its start/end limits, not the trimmed cutting segments, which intentionally skip the parts. It conservatively checks placed part bounds (including edge contacts), so a cutoff through a concave recess can also move ahead of that part. Definitions are matched by drawing identity, not their displayed names. A cutoff part with no matching definition is conservatively ordered before all ordinary parts.

This rule runs when applying automatic sequencing, after reversing the exit-first sequencer route into cutting order. Manual sequence edits are still manual; adding or moving cutoffs does not automatically reapply this rule. Reapply Part Sequencing after layout changes and review the resulting rapids before posting. Regeneration and saving/reloading retain the applied mixed sequence.

The all-plates command uses `PlateSequencing.ApplyAll`, which snapshots the target plate references before sequencing. Reordering parts raises collection events that can replace the nest's trailing empty plate; those events must not invalidate the batch's iteration or skip any original plate. This snapshot is not a transaction or a concurrency guard: sequencing still runs synchronously on the owning thread, using the same per-plate cutoff rules.

## Rerunning, editing, and saving

The command is one-shot; spacing and minimum-tail inputs start at their defaults each time the dialog opens. Generated lines are ordinary cutoffs and can subsequently be dragged, deleted, or sequenced with the existing tools. Moving parts regenerates their trimmed segments but does not reposition the cutoff grid or recalculate the retained tail automatically.

Rerunning unchanged suppresses equivalent existing full-span lines. A limited cutoff at a proposed line is a conflict requiring manual review, not permission to replace it or add overlapping NC moves. Existing definitions are never silently deleted or expanded.

Saving `.nest` retains ordinary cutoff positions, axes, limits, and sequence. Loading regenerates cutoff programs using the reader's default cutoff settings; exact toolpaths made with nondefault cutoff settings are not guaranteed to round-trip. Review regenerated paths before posting.

## Implementation boundary

`AutomaticCutOffPlanner` in Core builds detached definitions and diagnostics without changing the input plate. `AutomaticCutOffOptions.MinimumTailLength` is a finite, nonnegative distance in model units; its programmatic default of zero preserves the previous behavior, while the desktop explicitly supplies its unit-aware 12-in / 304.8-mm default. `AutomaticCutOffBatch.Create` plans an ordered plate list, and `Apply` replans the complete list before mutating any plate, refusing a blocked batch and recovering touched cutoff state on exceptions. Callers must prevent concurrent edits throughout planning/apply. The desktop dialog renders the active plate's detached preview through `PlateView.SetActiveParts`; both menu commands apply through the shared batch service, which adds definitions to `Plate.CutOffs` and uses `Plate.RegenerateCutOffs`. It must not accept preview parts directly, because doing so would bypass cutoff persistence and regeneration. There are no new nesting, post-processing, or `.nest` format rules.

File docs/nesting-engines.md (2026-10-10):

# Nesting engines

Whole-job engines implement `INestingEngine.Solve(NestJob)` and are selected by name through
`NestingEngineRegistry`. Every automatic nesting front end validates engine output the same way;
see [automatic nesting and validation](automatic-nesting.md).

## Built-in engines

Engines are named for the jobs they suit, not for how or by whom they were built. Engine code lives
in `OpenNest.Engine/NestingEngines/<Name>/`, its tests in `OpenNest.Engine.Tests/NestingEngines/`.

| Engine | Best for | Method |
|---|---|---|
| Default | Any job; used when no engine is named | Runs Irregular, then Rectangles, checks both layouts with the layout check and keeps the best: valid first, then fewest unplaced parts, then lowest salvage-credited cost; ties keep Irregular |
| Rectangles | Plain and near-rectangular plates | Each part packed as the box of its material at its minimum-area rotation, using a maximal-rectangles free list; stock chosen sheet by sheet by salvage-credited look-ahead cost |
| Irregular | Irregular profiles | No-fit-polygon frontier packing with gap filling and best-fit pairs, six whole-job strategy variants and a tail re-plan |
| StockLadder | Caller-supplied stock ladders | Constrained-first fill with equivalent-demand area repacking |
| Fill, Strip, Vertical Remnant, Horizontal Remnant | Single-strategy fills | The fixed placement strategies behind interactive fill; Fill is the multi-phase lattice fill (linear, pairs, rectangle best-fit, remainder) |

Neither Irregular nor Rectangles wins every job, even within its own lane, so Default runs both
rather than choosing by part shape; Rectangles adds little time and is also the fallback when an
Irregular layout fails the check. A candidate that throws is skipped. Default routes the whole job:
engines cannot share a sheet, so a job mixing plain and irregular parts goes to both engines whole.
A future circle/ring engine joins Default as another candidate.

Rectangles places irregular parts validly, but only as their bounding boxes; it never nests into a
notch or hole. Box sides account for how the layout check flattens arcs, so round-edged parts stay
valid at box contact.

Interactive/full-area box packing uses the same 90% work-area slack allowance as Rectangles.
A free box may absorb a slightly oversized side only at its right/top edge when that edge
coincides with the plate work-area boundary. Internal leftover edges keep the strict packing
tolerance, and actual part dimensions still determine spacing away from the plate boundary.

Irregular keeps nominal orientation bounds for line-only outlines, so an allowed rotation can
fit exactly between the configured plate-edge gaps. These bounds use original rotated line
endpoints, retaining material extents even when polygon cleanup discards short-edge chains.
Curved outlines retain conservative flattening-error padding. This does not relax part-spacing
footprints, no-fit polygons or layout validation tolerances; a part extending beyond the accepted
work-area bounds remains invalid.

Irregular fills gaps and open notches using outer profiles; it does not yet place parts inside
enclosed cutouts. For a part with two or more copies it also offers its best-fit pairs (two copies
interlocked, as the Best Fit viewer shows them) alongside the single copies, and places a pair
where both members' free regions allow it. Each pair's internal spacing is re-checked with the
layout check before it is offered, and only rotations the part's policy allows are used. A pair
may introduce legal rotations beyond the sampled single poses; these remain eligible even when
none of the sampled singles fits the stock. Both members block space separately, leaving their
notches and intervening gaps available for later parts. Concave no-fit polygons are prepared
with a single boundary/containment union.
Any remaining numerical hole is filled only when its entire ring is certified to lie in forbidden
space, preserving genuine enclosed placement pockets without changing spacing tolerances.

When remaining demand exceeds two, Irregular also offers Fill patterns as optional
multi-member candidates, not as solid bounding boxes or a whole-job Fill fallback. It searches
the empty work area and physical leftover space for up to two high-area rectangles. Occupied
outlines are expanded by part spacing before rectangle search. Each sheet prepares blocks initially
and after its first placement, for up to four high-demand-area types; each type has at most eight
new Fill preparations per spacing per solve. Repeated rectangles reuse private drawing/candidate
caches. Quantity-one and quantity-two requests never run block Fill.

Block members are trimmed to remaining demand, mapped back to source-frame rotations, and checked
for legal rotations and internal material clearance before competing with singles and pairs.
Group-only rotations do not expand the single-part rotation choices. Placement intersects all
member free regions and subtracts each placed member separately, preserving usable gaps. A failed
or invalid Fill proposal leaves singles and pairs available. Large enclosed-pocket blocks remain
pending the hole-geometry integration; containment cutting order and shop-use safety acceptance
remain separate sequencer/verification work.

## Filling cutouts (not yet in production)

Placing parts inside another part's enclosed cutout is being built as a step that runs before any
engine, so every engine benefits. Only an internal test-only pipeline preview calls it: a part
inside a cutout must be cut before the cutout's contour, and the cutting/post safety gates are
not complete. Ordinary whole-job calls do not enable this path.

`CutoutLatticeFill` (`OpenNest.Engine/Jobs/Cutouts/`) fills one closed cutout with copies of one
part. It runs Fill over the cutout's bounds plus one part step on every side, then shifts
that lattice across a grid of offsets of up to half a step each way. At each offset it keeps the
copies whose spacing-grown outline lies inside the cutout, using the part's inner-fit region of
the inscribed, flattened cutout, and the offset keeping the most copies wins. Every returned pose
is then checked against the frame and the other copies with `NestLayoutCheck.Clears`, the test the
layout check uses. The method suits many small copies in a large cutout; a few large inserts are
meant for no-fit-polygon placement. Fill can return different, equally scored lattices on repeated
calls for some parts, so results are not yet guaranteed identical between runs.

The internal `CutoutRouter` can propose copies from the shifted lattice, then search bounded
inner-fit/NFP sample points for remaining copies and other insert requirements. It keeps
original requirement IDs, reindexes accepted copies and checks clearance against the frame
and every previously accepted insert. Lattice shifts account for occupied poses before
quantity trimming; a pre-fill work limit declines giant grids and lets bounded NFP sampling
try instead. A null NFP proposal is not proof of geometric impossibility. No material-area
ratio cutoff rejects a possible placement: the measured 0.10 and 0.35 ratios guide
search order only. Below 0.10 it starts with Fill for three or more copies; between
0.10 and 0.35 it compares Fill-plus-NFP with NFP-only counts; above 0.35 it tries
NFP first, then Fill if demand remains, taking the higher-count valid proposal.
An 0.20 NFP-only rule would lose a second 4-inch square in a 10-inch round hole.
Six geometry-only, anonymized real-job probes and neutral ring fixtures informed
the search-order hints; these limited cases are not a global density guarantee.
The internal `NestPipeline.RunCutoutPreview` builds quantity-one proxy instances for eligible
closed-cutout frames. It considers legal frame rotations without outer-perimeter symmetry
reduction, shifts insert rotation policies into the local frame, and reserves certified router
poses by original requirement ID. It can fill multiple holes and repeated/different frame
requirements; inserts with a different priority or their own cutouts stay independent, so
bundles remain flat. It uses the largest offered spacing for every bundle because the current
job contract cannot condition insert demand on the stock selected later. Remaining demand is
offered to the selected engine once. Only actually placed proxies expand to original frame and
insert identities. An unplaced proxy's reservations return to the original unplaced demand;
they cannot be packed retroactively in that same solve. Engine indices and metadata are checked,
then every physical pose, stock, rotation, quantity and fulfillment is independently validated
before binding caller drawings. Incomplete, forged or geometrically invalid composites return
no bindable plates even with invalid-result consent. Candidate evaluation progress is forwarded
with unverified proxy commitment counts zeroed; transformed proxy commits are hidden. Physical
commits are reported only after physical validation. Preparation is bounded to 32 bundles
and 16 base sweep-angle samples per frame (automatic quarter-turns are all retained);
remaining copies stay ordinary requirements. Fixed legal proxy orientations are a
conservative search choice, not full engine choice among all legal orientations; unsupported
bundles remain ordinary independent requirements. This is an internal pipeline path, not a
production setting or cut-ready nest. Cutting/post safety remains pending before enablement.

## Renamed engines

The registry maps names used by earlier releases (the first two shipped as plug-ins) so saved
desktop selections, scripts and API requests keep working:

| Old name | Now |
|---|---|
| `Opus55NestingEngine` | Irregular |
| `RectanglesNestingEngine` | Rectangles |

In v0.3.0 and earlier, `Default` was the multi-phase fill engine now named Fill. `Default` now names the
choosing engine above, so saved selections, scripts and API requests that name it get that
engine. Fill-strategy calls (interactive fill, `PlateFillService`, console fill without
`--autonest`, MCP fill tools) still read `Default` as Fill.

Gpt6Astra and Qwen38FlashNext are no longer shipped and have no alias. A saved selection of either
falls back to the default engine with the usual status-bar warning.

## Changing an engine

- A change lands only when it beats the engine's current result on `OpenNest.Benchmark` for the
  jobs that engine targets, with every layout valid. Report cost, validity, unplaced parts and time.
- Placement must be deterministic: no clocks, unseeded randomness or environment variables. Budget
  work by counting it; wall time may stop work only through the cancellation token.
- Keep each engine's tests passing, including `EngineContractTests<TEngine>` (quadrants, overflow,
  priority, cancellation, stock and plate limits, determinism). Every layout in those tests is
  checked with `NestLayoutCheck`, the benchmark's validator.
- Engines may share code. Move a helper into shared Engine code when a second engine needs it,
  rather than copying it.

## Plug-ins

External engines still load from an `Engines/` folder beside the desktop, console, MCP or benchmark
executable. A plug-in implements `INestingEngine` with a public parameterless constructor and
registers under its CLR type name. A plug-in whose name matches a built-in engine, or a renamed
engine's old name, is skipped: a leftover `OpenNest.Engine.Opus55.dll` cannot shadow Irregular.
Leftover Gpt6Astra or Qwen38FlashNext DLLs still load as ordinary plug-ins until deleted.

## Cost basis and heuristic limits

`NestPlateStock.Cost` is nullable, immutable and per physical sheet. Every available
stock must have a finite positive cost, or all must omit it. Omitted costs preserve
area scoring. The original constructor and area-valued `NetSheetArea` and obsolete
`EstimateNetArea` APIs retain their units. `NetSheetCost` applies proportional salvage
to explicit costs; geometric area still controls fit, utilization and material ordering.

Rectangles uses net cost in sheet trials and remaining-material estimates. Irregular
uses it in look-ahead, strategy comparison and equivalent-demand tail replacement.
StockLadder ranks net cost per placed material area and uses total net cost for
consolidation. Default compares valid equally fulfilled results by generic job score.
Fixed Fill/Strip/remnant strategies rank priority fulfillment first, then net cost
for priced stock (gross area for legacy unpriced stock), then existing stable ties.
None guarantees globally optimal purchasing or explores every combination of patterns.

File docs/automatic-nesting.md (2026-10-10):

# Automatic nesting pipeline

`NestPipeline.Run` is the shared whole-job boundary in `OpenNest.Engine`:

1. Snapshot caller requirements and stock into a `NestJob`.
2. Resolve the selected name through `NestingEngineRegistry` (built-ins and plug-ins use the same path).
3. Run the engine without mutating caller drawings or plates.
4. Check returned placements with the independent `NestLayoutCheck` used by the benchmark.
5. Bind a representable result back to the caller's drawing references; the caller decides whether to commit it.

`NestStockBuilder.FromTemplate` snapshots sheet options and spacing settings for multiple-sheet jobs. `SinglePlate` offers exactly one physical sheet, regardless of the legacy plate repeat quantity. `NestPipelineCommit.ApplyToEmptyPlates` applies accepted desktop proposals to empty/new plates with the checked size, quadrant, spacing and quantity-one semantics. It never fills occupied plates.

## Desktop Auto Nest

Every engine selected in **Nest > Auto Nest** uses the pipeline. Part-First and its sorting controls are removed. Use interactive Fill Area/remnant tools for leftover space on occupied sheets; these are not whole-job nesting.

Auto Nest starts on empty/new sheets and does not change existing populated plates. Stock Options offers sheet sizes and salvage settings; minimum salvage size is part of that section, not a Part-First option. When enabled, its grid keeps a blank last row for adding another size (`W x L`) and cost, including after loading saved options. Unused blank rows are not offered as stock. The maximum remains 100 physical sheets per run.

Progress is owned and modal so the input drawings cannot be edited while a worker uses them. Stop or closing progress cancels and discards the whole proposal. The dialog waits for the worker to finish; no engine has an Accept-early button on this path. A plug-in that ignores the cancellation token cannot commit its late result.

Every invalid result shows the validation report before any plates are changed:

- **Discard** is the default button and the Escape action. No proposed parts or sheets are applied.
- **Keep anyway** requires an explicit click and keeps the entire representable proposal, then enables Overlap Check.
- Malformed output (unknown requirements or nonfinite poses) is not keepable. It cannot be faithfully represented as the proposed layout; no partial/truncated proposal is offered.

Overlap Check displays material overlaps, not every spacing/stock/rotation failure in the report. A layout passing validation may still be incomplete; completeness and stop reason are separate from geometric validity. This check does not replace pre-post CNC verification.

The selected engine is saved in `%APPDATA%\OpenNest\engine-selection.json`.
Selection is restored after plug-ins load. A saved name from an earlier release
maps to the engine that replaced it (see [nesting engines](nesting-engines.md)).
If the saved engine is unavailable, Default is selected and the status bar
reports the fallback; startup does not replace the saved missing-engine preference.

## Integration constraints

Callers must hold drawings and target state stable from snapshot through attachment. Do not append whole-job placements to an occupied target or flatten multiple returned sheets onto one plate: that would commit a layout different from the one checked. Do not trust arbitrary engine fulfillment metadata as a substitute for counting returned placements.

Interactive fills are outside this contract and still use `PlateFillService`. The benchmark invokes the same independent validator.

The pre-pipeline multi-plate orchestrator and plate-size optimizer have been removed from `OpenNest.Engine`; this is a source and binary break for external code that called them. Whole-job callers use `NestPipeline.Run` (or implement `INestingEngine` as a plug-in); multiple stock sizes and salvage credit are expressed as job stock and `NestJobOptions`.

## Console and MCP

Console `--autonest` uses the jobs engine named by `--engine` (Default when omitted) against one physical sheet. The selected plate's old parts are replaced only after acceptance; other plates are unchanged. Default demand is still one of each drawing unless `--quantity` is supplied. A partially fulfilled, valid result may be saved; a successful placement is not a claim that all demand was met.

Invalid output is printed and rejected with exit code 2 without saving or posting. `--allow-invalid` explicitly accepts representable layout violations. Malformed output, multiple returned sheets, and zero placements are never saved by this path. Unknown engines exit 1. `--autonest --keep-parts` rejects an occupied target: use the plain interactive fill path for existing obstacles instead.

MCP `autonest_plate` requires an empty target. The stdio server serializes all tool calls sharing its mutable session, so another request cannot change drawings or occupy a target during a solve. `allow_invalid` defaults to false. It reports violations and makes no changes on rejection, including with an override when the output is unrepresentable or contains multiple sheets. `engine` defaults to Default, and its description lists the built-in engines with what each suits. Fill tools (`fill_plate`, `fill_area`, `fill_remnants`, `pack_plate`) remain separate and default to the Fill strategy. Console and MCP load jobs plug-ins from `Engines/` beside their executable.

MCP `pack_plate` and `autonest_plate` report each requested drawing's newly placed count and remaining quantity, indexed by request; partial fulfillment is explicitly warned about. Per-sheet ratios are not enforced or required: an uneven sheet is acceptable if the remaining quantities are placed elsewhere in the nest. These two plate tools operate on a single selected plate and do not automatically finish a multi-sheet job; callers can use `autonest_job` for that. Duplicate request tokens and ambiguous drawing names are refused before placement. A zero-quantity pack request places zero parts for that drawing; negative quantities are rejected.

`autonest_job(plateIndex, drawingNames, quantities, engine?, no_new_plates=false, sheets?)` is the whole-session completion path. Quantities are total targets across existing placed parts (physical plate quantity included) plus newly proposed sheets. Without `sheets`, the selected empty cutoff-free plate supplies stock size, spacing, quadrant, grain and cutting settings; other empty plates with equivalent persisted settings may be reused first, then additional matching plates are created as needed. `no_new_plates=true` limits this legacy solve to existing matching empty plates. The request uses the independently validated `NestPipeline` and commits only when every requested quantity is met; invalid, incomplete, cancelled or unknown-engine proposals leave existing plates and counts unchanged. A no-placement solver result is not proof that geometry cannot fit. `pack_plate` and `autonest_plate` remain single-sheet operations.

For finite mixed-size inventory, supply `sheets` as an array, for example `{"plateIndex":0,"drawingNames":"large,small","quantities":"1,1","engine":"Rectangles","sheets":[{"width":60,"length":120,"quantity":1},{"width":48,"length":96,"quantity":2}]}`. Width and length have the same units and orientation as `create_plate`. Every row's positive integer `quantity` is the total physical sheets available for this solve, including any compatible pre-created empty plates; it is never a `Plate.Quantity` repeat multiplier or additional stock. The selected plate supplies common spacing, edge spacing, quadrant, grain and cutting settings, but is reused only if its size matches a chosen sheet. Other compatible empty sheets can be reused; occupied or cutoff-bearing sheets cannot. Only needed different-sized sheets are created. Duplicate size pairs, nonpositive or nonfinite dimensions, unusable work areas, nonpositive quantities, an empty list and excessive total inventory are refused before solving. `sheets` cannot be combined with `no_new_plates=true`. Omit `sheets` to retain the previous single-size behavior. Successful output reports `stock-0`, `stock-1`, etc. in input order with used/remaining/reused/created physical counts, plus committed session plate index to stock ID and per-drawing totals. Stock is request-local, not a persistent purchasing catalog. Unused empty templates may be omitted by the `.nest` writer on save.

MCP `delete_plate(plateIndex)` removes only a sheet with no parts and no cutoff definitions, from either loaded or newly created session plates. Occupied, cutoff-bearing and invalid indices are refused without changing the session. After deletion every later index shifts down by one; inspect `get_plate_info` before further edits. This is session cleanup, not a data purge or a save-time option. `save_nest` lists all session plates in its response, but the existing `.nest` writer omits empty cutoff-free plates from the serialized file; reloading may therefore have fewer plates than the response says. There is no opt-in switch to preserve empty plates in the file.

### MCP engine development harness

`test_engine` builds and runs `OpenNest.Console` in a configured, trusted checkout.
`nestFile` is required; there is no machine-specific sample default. Drawing,
plate and output arguments and the stdout / `=== Errors ===` / nonzero-exit
response format are unchanged. Relative nest/output paths resolve from the MCP
server's working directory, before launching the checkout's console.

The existing .NET host configuration accepts:

- `EngineHarness:SourceRoot`: required absolute checkout path containing
  `OpenNest.Console/OpenNest.Console.csproj`.
- `EngineHarness:DotnetPath`: optional existing absolute executable path;
  defaults to the dotnet host in the active .NET installation, never a PATH search.
- `EngineHarness:TimeoutSeconds`: positive integer, default **120**, maximum
  2147483. The single deadline covers build/run, process exit and both concurrent
  output drains. MCP request cancellation uses the same bounded path.

For environment variables, use `EngineHarness__SourceRoot`,
`EngineHarness__DotnetPath` and `EngineHarness__TimeoutSeconds`. These are
server/operator settings, not caller-supplied executable or checkout overrides.

Timeout/cancellation returns a clear error, kills the owned live process tree,
waits up to five additional seconds for direct-process cleanup, and closes local
pipe readers. Cleanup failures are reported. A descendant already detached when
its parent exits cannot reliably be found by `Process.Kill(entireProcessTree)`;
it may remain alive, but inherited pipe writers cannot hold the tool open.
The harness does not scan for or kill unrelated processes. Windows process-tree
semantics still need Windows runtime acceptance; the private process regressions
also execute on Linux without customer nest files.

## .NET API and saved responses

Set `NestRequest.Engine` to a registered engine name; null retains `PlacementStrategy` / legacy `Strategy` behavior. Library hosts own plug-in discovery via `NestingEngineRegistry.LoadPlugins` before calling the API. Explicit request requirement IDs are preserved in response fulfillment even when multiple requirements use the same source DXF.

The API returns a detached proposal. `ValidationStatus` is `Valid`, `Invalid`, or `Unrepresentable`, and `Violations` lists the problems. Representable invalid proposals retain their parts for caller review; unrepresentable proposals contain no sheets. Consumers must inspect validation before applying, quoting or posting the proposal. `Status` describes fulfillment, not acceptance: counts, stock usage and completeness are derived from returned placements rather than trusting plug-in summary metadata.

Response archive schema 3 persists validation status and violations. Older archives with no validation metadata load with null status; null must not be interpreted as a successful check. Saving a proposal archive records it and does not authorize CNC posting.

## Verification

`dotnet test OpenNest.FrontEnd.Tests/OpenNest.FrontEnd.Tests.csproj` exercises Console, MCP and API rejection/override, cancellation, physical-sheet settings, response IDs and archive round-trips. Its current target matches MCP's `net8.0-windows` marker but does not use WindowsDesktop and executes on Linux as well as Windows. It is included in the solution and Windows test workflow. Desktop interaction tests remain in Windows-only `OpenNest.WinForms.Tests`.

## Stock costs

Auto Nest Stock Options accepts a generic **per physical sheet** Cost. Enter positive
finite costs on every active row in one common unit (purchase price, area, or another
consistent scalar). All-zero rows retain legacy area scoring: zero means unspecified,
not free stock. Negative/nonfinite costs and mixed zero/positive rows are rejected
before solving. The blank add row is ignored.

MCP `autonest_job` accepts optional `cost` on each `sheets` row, alongside `width`,
`length` and positive finite `quantity`. API `NestRequestPlate.Cost` uses the same
nullable contract: omit every cost for area scoring, or supply strictly positive
finite values for every available row. Explicit zero is invalid in these requests.
Engine stock with quantity zero is unavailable and does not select the cost mode.
MCP continues to reject duplicate sizes; API/engine stock IDs keep independent inventory.

With prices, gross sheet cost is the supplied value. Salvage is still computed from
the largest qualifying material-edge offcut; net cost is
`Cost * (NetSheetArea / SheetArea)`. Set desktop salvage rate to zero for purchase-price
comparisons. Entering prices preserves the selected salvage settings. MCP and API
currently disable salvage. Without prices, scores retain their existing area units
and tie ordering; fixed strategies retain their legacy no-salvage area tie-break.

Desktop reports gross cost, estimated salvage credit and net score. MCP reports
`basis`, each stock's used physical count, supplied cost and gross subtotal, plus
gross total, estimated salvage credit and net score. API exposes these under `Costs`
(`Basis`, `Stock`, `GrossTotal`, `SalvageCredit`, `NetScore`) and persists them in
quote archives. For example, two sheets costing 25 each report gross total 50;
with salvage disabled, credit is 0 and net score is 50. `area` identifies fallback
scoring; `supplied-cost` identifies explicit prices. Totals cover the returned proposal,
not previously occupied session sheets, and exclude penalties for unplaced demand.
Invalid API proposals have no cost summary. Overflow fails instead of becoming a score.

An accepted MCP solve stores requested drawing quantities and offered stock prices;
save/reopen preserves them and existing nest metadata. Rejected/cancelled proposals
change neither requirements nor options. Inventory remains request-local; saved
options are offers, not a per-sheet purchase ledger. These are cost-aware heuristics,
not global cost optimizers; validation and fulfillment remain required.

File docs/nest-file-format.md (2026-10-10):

# Nest file format and saved cutting state

`.nest` is a ZIP archive with additive version-2 JSON metadata in `nest.json`.
Old files remain readable. Older applications ignore the new cutting-state fields;
opening and saving with an older application loses that state.

## Job metadata

`nest.json` carries the workflow fields shown in the nest info dialog:
`name`, `customer`, `dateCreated`, `dateLastModified`, `notes`, `material`,
`thickness`, plus `status` (`"Quote"`, `"ToBeCut"`, `"HasBeenCut"`) and `madeBy`.
Status and made-by are additive: files written before them load as Quote with an
empty maker, and an unrecognized status value likewise falls back to Quote.

## Programs and placements

- `programs/program-N` is drawing N's clean G-code program; optional
  `programs/program-N-subs` contains its hole sub-programs.
- Each serialized plate has a one-based `id`. Its `parts` array excludes cut-offs;
  each placement retains `drawingId`, `x`, `y`, and `rotation` (radians).
- A placement with `HasManualLeadIns` also writes `parts/plate-P/part-K`, and
  `parts/plate-P/part-K-subs` when it has hole sub-programs. P is the serialized
  plate ID; K is the zero-based index in that plate's serialized parts array.
  Empty plates and cut-offs do not consume these part indices.
- The placement's `program` field references that ZIP entry. Its G-code is saved
  in the already-rotated local part frame, with the placed origin at `(x, y)`.
  Existing `:LEADIN`, `:LEADOUT`, and other layer tags, tab gaps, and G65 calls
  are retained rather than regenerated by a cutting strategy during load.
  Hole IDs may be negative: they are identifiers, not validity sentinels.
- `drawingHash` protects against restoring obsolete cutting paths after an
  externally edited drawing. It is uppercase SHA-256 of UTF-8 text composed of
  the main text's decimal UTF-16 character count, `:`, main text, and sub-program
  text (empty when absent). The hash includes both drawing entries so changing a
  hole alone invalidates the placed cutting program. Text is read without a BOM;
  otherwise whitespace and line endings participate in the hash.

The reader constructs and places a clean part first, then installs its saved
program without rotating it again. The drawing reference remains authoritative
for Remove Lead-ins: removing them restores the clean drawing at the saved pose.
Successful restoration marks the part as carrying lead-ins and restores its
`leadInsLocked` flag. The per-part `CuttingParameters` reference remains null;
the saved program, not strategy regeneration, determines the cutting geometry.

Missing `program` references in legacy files load clean and silently, even when
old transient flags were true. A missing or mismatched drawing hash likewise
loads clean silently. A referenced but missing, unparseable, or motionless part
program, or an unresolved/empty hole sub-program, leaves that part clean and
unlocked without discarding the rest of the nest. `NestReader.Warnings` identifies
the plate, zero-based part index, and entry; File > Open displays these warnings.
The program reader is not a general G-code or geometric safety validator; the
saved cutting geometry is not validated against the drawing.

## Plate cutting parameters

Each plate's optional `cuttingParameters` stores the settings used by Assign
Lead-ins and Place Lead-in. Missing settings stay null, preserving the old default
selection behavior. `OpenNest.IO.CuttingParametersSerializer` owns the shared
cross-platform DTO mapping; the desktop settings serializer delegates to it so
existing saved settings keep their JSON contract. Settings are independent of
the saved part programs: restoring settings never regenerates those programs.

## Drawing edits

`DrawingProgramSnapshot` captures serialized main and hole-program text before
the converter is loaded. After an accepted edit, only parts referencing drawings
whose program text changed are rebuilt (lead-ins, tabs, and locks cleared); their
location and rotation remain unchanged. Reference identity, not editable names,
keys this comparison. The desktop invalidates the affected layout graphics.
Name, quantity, and color edits leave placed programs alone. The properties
editor previously called `LayoutPart.Update`, a color refresh, not `Part.Update`;
it now explicitly refreshes only the edited drawing's layout colors.

## Verification and limits

The automated tests cover save/reopen/re-save, rotated/manual/locked parts,
lead-outs and tab gaps, hole binding, clean removal, stale drawings, damaged
entries isolated from other parts, plate settings, and CI Fiber posting before
and after reload. Drawing-change decision logic runs on Linux; desktop rendering,
dialog values, and clicks require Windows acceptance.

Known separate issue: the cutting strategy currently labels contour cuts
`Display`. CI Fiber includes them, but GravographIS skips Display. Saving restores
the existing layers; this change does not alter the strategy or either post.
Future hardening: make numeric G-code serialization/parsing culture-invariant
as a coordinated compatibility change; do not change just one side. Program
content deduplication is optional and must not change per-part ownership.

## Stock-option prices

The existing `plateOptions` entries retain width, length and `cost`; no new `.nest`
format version is required. Legacy zero cost means unspecified, not a free sheet.
Positive costs are generic per-sheet values in caller-consistent units. Solving
requires all available options to be priced or all to be unspecified.

Desktop and accepted MCP/API jobs retain offered options (API rows with zero available
quantity are excluded because `.nest` options do not retain inventory). MCP save also preserves
loaded job metadata, plate defaults and salvage settings, and accepted whole-job
requirements are stored on drawings. Options do not persist finite inventory or
associate a historical purchase price with each physical sheet. API quote archives
additionally retain request costs and validated proposal cost summaries; old archives
without summaries load with `Costs == null`.

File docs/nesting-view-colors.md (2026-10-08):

# Nesting-view colors

Choose **Tools > Options > Color scheme > Workshop**, then **Save** for a
high-contrast per-drawing view:

- Generated fills: hue advances by 137.508 degrees per drawing (skipping the
  green band reserved for etch) and cycles through eight saturation/lightness
  tiers on an irrational stride, so parts sharing a sheet stay far apart in
  color. All copies of a drawing keep its color.
- Thin dark gray `#303030` cut outlines.
- Bright green `#00FF00` etch strokes, independent of the part fill, so marks
  that are not cuts cannot be mistaken for part outlines.
- Pale gray `#F2F2F2` sheet and neutral gray background.

The generator continues beyond the twelve preview samples instead of wrapping
through a short palette. It maximizes separation between consecutive drawing
indices, not spatial neighbors; very large jobs can still place similar colors
side by side. This is not a colorblind-safe or perceptually uniform palette. Selected parts retain the
standard translucent blue highlight; etch and cut colors stay unchanged.
Classic, Pastel and Dark remain available; saved scheme choices are not changed.
Applying a scheme recolors drawings in currently open nests. Drawings may retain
custom or saved fill colors; open a saved nest before applying Workshop to recolor it.

In plate views and drawing thumbnails, scribe/etch motions have a separate stroke
from material cuts. A closed etched circle or lettering does not make a hole in
the displayed part fill. An etch-only part remains selectable by its closed
mark in the plate view; etch lines still do not become cut material. Selection
changes the part highlight, not the etch color.
Lead-in/out strokes keep their existing orange-red appearance. Preview placements
show etches too. A cut coincident with an etch is drawn over the etch, so it is not
hidden by the mark.

This is a display aid, not a geometry classifier or machining-safety certificate.
Only motions classified as `Scribe` receive etch styling; a line incorrectly
classified as `Cut` remains a cut line. Drawing geometry, layer classifications,
cutting plans and post-processor output are not changed by the renderer. The CAD
conversion/program-editing views retain their own source/classification colors.

## Custom scheme files

Scheme JSON files in `Schemes/` beside the application may specify `etchColor`
and `partOutlineColor` as `#RRGGBB`. Optional `selectedPartColor` specifies an opaque
selection fill; missing or null retains the legacy translucent selection highlight.
Missing `etchColor` uses the bright green etch default.
Missing or null `partOutlineColor` retains the legacy darker-than-fill outline.
Optional `useGoldenAngleColors: true` selects generated drawing colors; missing
or false keeps the explicit `partColors` palette and its legacy cycling behavior.
Workshop tests check the first 1,000 generated fills stay far in RGB distance
from both the dark cut outline and the bright green etch stroke, and that no
fill hue falls in the etch green band. Selected rendering has separate bitmap tests.
Custom or previously saved fills are not automatically contrast-corrected;
apply Workshop after loading the nest to recolor its drawings. Existing scheme
names, saved choices, custom palettes and geometry remain unchanged.

## Verification

On Windows, run:

```powershell
dotnet test OpenNest.WinForms.Tests/OpenNest.WinForms.Tests.csproj -c Release --filter FullyQualifiedName~EtchDisplayTests
```

Then inspect an actual nest with both cuts and etches: select/deselect and move a
part, zoom in/out, inspect drawing thumbnails, and switch away from Workshop and
back. Confirm the marks remain readable, closed marks stay filled and real holes
remain holes. Automated bitmap tests verify the rendering rules, not an operator's
assessment of readability on a particular display.

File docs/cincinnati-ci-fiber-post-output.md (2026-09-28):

# Cincinnati CI Fiber Post Output Reference

Project-written summary of `OpenNest.Posts.CincinnatiCIFiber`, not a vendor
manual or a machine-operation guide. For the separate CL-series post, see
[Cincinnati output](cincinnati-post-output.md).

Controller reference used during development: Beckhoff *TF5200 | TwinCAT 3 CNC
Programming manual*, version 1.33, May 19, 2026
(`TF5200_programming_manual_en.pdf`). Obtain the applicable documentation from
Beckhoff and Cincinnati. Vendor PDFs and full-text extracts stay outside source
control; redistribution permission has not been established.

## Output contract

The current [writer](../Posts/OpenNest.Posts.CincinnatiCIFiber/CIFiberProgramWriter.cs)
uses the Cincinnati machine-sample convention, not a generic TF5200 laser API:

- Header: nest/configuration/material comments; `V.E.MATERIAL`, `V.E.THICKNESS`,
  `V.E.X_SIZE`, `V.E.Y_SIZE`, and `V.E.UNIT`. Sheet weight is omitted by default.
- Startup: `G90`, `L PROGRAMSTART.NC`, then `P3=V.E.R3`, `$GOTO NP3:`, and `N0:`.
- Parts follow plate order. `V.E.R4` identifies the part within its sheet;
  numbered contour labels and `V.E.R3` count up through the program for restart
  lookup (they restart at 1 in each per-sheet program).
- Each contour: `/L "L0"`, restart number, rapid to pierce, then interior
  `/L "L2"` with `G41` or exterior `/L "L4"` with `G42`; linear lead-in,
  `/L "L6"`, cutting moves, and `/L "ZHSOFF"`.
- Tail: `/L "L0"`, `L PROGRAMEND.NC`, the pallet-change code (`M50`), `M30`,
  and `%`.
- Motion endpoints are sheet-absolute XY. Arc `I`/`J` are offsets from the arc
  start, matching the G162 convention; the post does not explicitly emit G162.
- Parts and sheet cut-offs post in the plate's cut sequence (`Plate.Parts`
  order, as set by Set Sequence or a sequencer). A cut-off is not moved after
  the parts. Each segment is an open
  line with no lead-in: rapid to its start, `/L "L4"`, `/L "L6"`, the `G1`,
  and `/L "ZHSOFF"`. No `G41`/`G42` is selected, because the line is the beam
  centreline and has no inside or outside. Whether the `L4` macro runs
  correctly without a following lead-in move has not been confirmed on the
  machine.
- Hole subprogram geometry is inlined. Suppressed moves and, by default,
  wholly scribe contours are omitted.
- Files use UTF-8 without a BOM and CRLF lines. Default accuracy is three decimal
  places: coordinates trim trailing zeros; dimensional header values retain them.

## Configuration and boundaries

See [CIFiberPostConfig](../Posts/OpenNest.Posts.CincinnatiCIFiber/CIFiberPostConfig.cs)
for macro names, material mappings, unit codes, precision, and table limits.
The post is named for the machine family; table size belongs in configuration.
In the desktop app these settings open in a sectioned editor (Machine, Sheets,
Material, Program output, Macros) with a material-code table; values are
validated and saved only when OK is pressed.

- Assign linear lead-ins before posting, including circular holes. The writer
  rejects missing or arc-first lead-ins. Its conservative rule cites the G238
  compensation-selection restriction in TF5200 §13.2.4.1; do not generalize it
  to every controller compensation mode.
- `/L` calls are skippable; `L PROGRAMSTART.NC` and `L PROGRAMEND.NC` are not.
  Macro bodies, process settings, restart handling, and compensation cancellation
  belong to the machine configuration. The post does not emit an explicit G40.
- `InchUnitCode` defaults to `1`; `MetricUnitCode` defaults to `0` but remains
  unconfirmed. Table limits compare directly with nest dimensions, without unit
  conversion. Do not assume changing the unit code establishes metric support.
- Plates without parts are not posted. With **One program per sheet** (the
  default) and more than one sheet, `JOB.cnc` is written as `JOB-1.cnc`,
  `JOB-2.cnc`, ..., each a complete program with its own sheet size and pallet
  change. This follows the CL-series batch rule (EM-423 §7.4: one sheet per
  program; the operator sets repeats). A single-sheet nest keeps the chosen name.
  Plate quantity is not written; repeat the program at the machine.
- With the option off, every sheet goes into one program: `/L "L0"` and the pallet
  change separate sheets, and the header carries the first sheet's size. Sheets
  of different sizes are rejected in this mode. Posting to a stream always
  produces one program, so it rejects a multi-sheet nest in per-sheet mode.
- `PalletChangeCode` defaults to `M50`, the Cincinnati pallet change: the machine
  sample ends `L PROGRAMEND.NC`, `M50`, `M30`, moving the cut sheet out for
  unloading before the program ends (CL-series manual EM-423 §3.50; confirmed by
  the machine owner).
- **Release blocker:** the single-program sequence between sheets (`/L "L0"`, then
  `M50`, then the next sheet with no new header or start macro) is inferred, not
  observed. Confirm it against a Cincinnati multi-sheet sample before release, or
  keep **One program per sheet** on, which matches the single-sheet sample.
- All programs are generated and every sheet is validated before any file is
  written, so a failed file post writes nothing. A failed stream post may leave
  partial output; discard it. Successful generation and tests do not establish
  that a program is safe to run on a particular machine.

## Verification

[Output-contract tests](../OpenNest.Tests/CincinnatiCIFiber/CIFiberPostProcessorTests.cs)
cover a square with a hole, coordinate transforms/formatting, lead-in rejection,
cut-off sequencing and output, table bounds, suppression/scribe handling, and
multi-sheet output in both modes. Run:

```sh
dotnet test OpenNest.Tests/OpenNest.Tests.csproj --filter FullyQualifiedName~CincinnatiCIFiber
```

Keep this summary aligned with the implementation and tests. Cite the relevant
manual section for controller rules and distinguish those rules from
Cincinnati-specific macros and behavior observed in a machine sample.

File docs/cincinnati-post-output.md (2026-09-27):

# Cincinnati Post Output Reference

Reference for the G-code structure emitted by `OpenNest.Posts.Cincinnati`.
Every code listed here maps to a section in the Cincinnati Laser Programming
Manual (EM-423 R-02/11). Section numbers in parentheses (e.g. `§1.52`)
refer to that edition. Obtain the applicable manual from Cincinnati; vendor
manuals are not bundled because redistribution permission has not been established.

This is a project-written implementation reference, not a replacement for the
machine's programming, operating, or safety documentation. Keep vendor PDFs and
full-text extracts outside source control; do not re-add them without permission.
For the separate CI Fiber post, see [CI Fiber output](cincinnati-ci-fiber-post-output.md).

If you add a new emission in the post, either cite the manual section it maps
to, or flag it here as a known custom extension. "Custom code" in this project
means something that is not documented in the manual but that the Cincinnati
control is known to accept — none exist today and we should not introduce any
without confirming the control behavior.

## Overall file structure

A generated file contains, in order:

1. **Main program** (`CincinnatiPreambleWriter.WriteMainProgram`)
   Preamble, unit/mode setup, initial library, variable-declaration call, one
   `M98 P<sheetSubNum>` call per plate quantity, and `M30` to end.

2. **Variable declaration sub-program** (`CincinnatiPreambleWriter.WriteVariableDeclaration`)
   Machine variables (`#number = value`) used across the nest, terminated
   with `M99`.

3. **Sheet sub-programs** (`CincinnatiSheetWriter.Write`), one per unique plate
   layout. A sheet sub-program contains the cutting sequence for a whole
   plate, either with features inlined or with `M98` calls into part
   sub-programs.

4. **Part sub-programs** (`CincinnatiPartSubprogramWriter.Write`), one per
   unique `(drawing, rotation)` pair, only emitted when
   `Config.UsePartSubprograms` is enabled.

5. **Hole sub-programs** (`CincinnatiPartSubprogramWriter.Write` reused with a
   `"HOLE"` label), one per unique hole geometry keyed by radius and lead-in
   normal angle.

Sub-program bodies start with a `:<subNum>` label and end with `M99`.

## Feature blocks

A "feature" is a single contour: lead-in → cut moves → lead-out. Each feature
block in a sheet or sub-program output follows this order
(`CincinnatiFeatureWriter.Write`):

1. `G0 X_ Y_` — rapid to the pierce point (§1.00).
2. Optional part-name comment, only on the first feature of each part.
3. `G89 P<library>` — load process parameters (§2.89). `P` is a library file
   name; the `(...)` trailing comment carries speed-class info.
4. `G84` (cut) or `G85` (etch / no-pierce) — pierce and start cut, or start
   cut without pierce (§2.84 / §2.85).
5. `M130 (ANTI DIVE OFF)` — disable anti-dive, only if configured (§3.130).
6. Contour moves:
   - `G41` (left) or `G42` (right) kerf compensation on the first cut move
     (§1.41 / §1.42), suppressed for etch features.
   - `G1 X_ Y_ [F<feedvar>]` — linear cut move (§1.01). Feedrate references a
     machine variable such as `#148` and is emitted only when it changes.
   - `G2 X_ Y_ I_ J_ [F<feedvar>]` (CW) or `G3` (CCW) — arc (§1.02 / §1.03).
     `I`/`J` are incremental offsets from the current position to the center.
7. `G40` — cancel kerf compensation (§1.40), only if it was applied.
8. `M35` (or `M135` if SpeedGas is enabled) — beam off (§3.35 / §3.135).
9. `M131 (ANTI DIVE ON)` — re-enable anti-dive (§3.131).
10. `M47` or `M47 P<distance>` — raise Z-axis, unless this is the last feature
    on the sheet (§3.47). A leading `/` (block delete, §5.6) is prepended when
    the configured override distance exceeds the default.

Sheet sub-program and sheet-level feature calls add `G92 X#5021 Y#5022`
(§1.92) at the top so the local origin is anchored to the machine's current
absolute position (`#5021`/`#5022` are the machine X/Y system variables).

## Sub-program call patterns

There are two distinct call-site patterns, depending on whether the call
targets a whole-part sub-program or a hole sub-program.

### Part sub-program call (`WriteSubprogramCall`)

Used when `Config.UsePartSubprograms` is enabled. The tool physically rapids
to the part corner, then G92 sets the current position as the local origin,
the sub-program executes in its own local coordinate frame, and G92 restores
the original absolute position after return.

```
G0 X<left> Y<bottom>          ; rapid to part bounding box corner (§1.00)
(PART: <name>)
G92 X0 Y0                     ; set local origin at current position (§1.92)
M98 P<partSubNum> (<name>)    ; call the part sub-program (§3.98)
G92 X<left> Y<bottom>         ; restore the sheet coordinate system (§1.92)
M47                           ; head raise unless this is the last part (§3.47)
```

This pattern uses G92 because the tool is physically positioned at the part
corner first. The sub-program's coordinates are part-local, so they are
interpreted against the new origin until G92 restores the sheet frame.

### Hole sub-program call (`WriteHoleSubprogramCall`)

Used for the `SubProgramCall` codes that a `ContourCuttingStrategy` emits for
each circular hole. Unlike parts, we do **not** want a physical rapid to the
hole center before calling — the sub-program's first rapid is the lead-in to
the pierce point, and the machine should travel directly from the previous
feature's end to that pierce.

```
G52 X<hole.x> Y<hole.y>       ; shift local origin to hole center (§1.52)
M98 P<holeSubNum>             ; call the shared hole sub-program (§3.98)
G52 X0 Y0                     ; restore the original coordinate system (§1.52)
M47                           ; head raise unless this is the last feature (§3.47)
```

G52 specifies the new origin in the current work coordinate system and — per
§1.52 — "does not move the cutting nozzle". The hole sub-program is written
in hole-local coordinates (origin at the hole center, produced by
`ContourCuttingStrategy`), so its first `G0 X_ Y_` resolves to `hole + local`
in absolute terms. That is the first physical motion, and it takes the tool
straight from wherever it was to the lead-in pierce point. G52 X0 Y0 cancels
the shift after `M99` returns control.
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

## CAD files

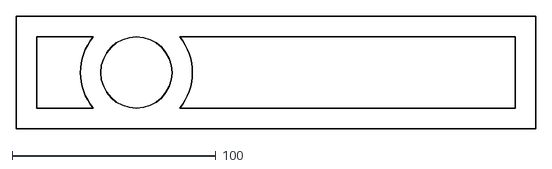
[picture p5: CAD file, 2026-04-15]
OpenNest.Tests/Splitting/TestData/split_test.dxf
255.0 x 55.0

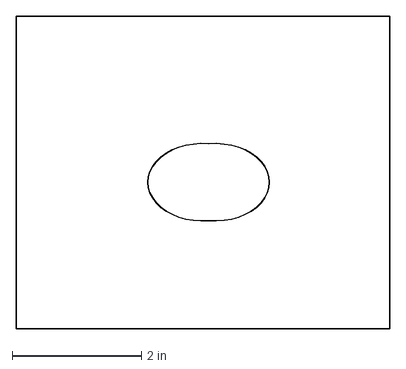
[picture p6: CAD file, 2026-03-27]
OpenNest.Tests/Bending/TestData/4526 A14 PT11 Test.dxf
5.79 x 4.84 in

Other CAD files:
OpenNest.Tests/Bending/TestData/4526 A14 PT45.dxf
OpenNest.Tests/Bending/TestData/4526 A14 PT11.dxf
OpenNest.Tests/Bending/TestData/4526 A14 PT23.dxf

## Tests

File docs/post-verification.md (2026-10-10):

# Verify a nest before posting

## Standalone desktop validation

Choose **Nest > Validate Nest...** to inspect all plates without running the cut
planner or selecting a post processor. The read-only **Validate Nest** window
checks overlapping material, missing lead-ins, and rapid crossings in the existing
placed programs and cutting order. Findings identify plate and part sequence
numbers in a read-only grid like the cut planner; incomplete or failed checks are
never reported as clear. Select a row to switch the main plate view to that plate
and focus the finding. The inspector opens at the right of the screen and can be
moved or resized. The details below the grid explain the selected warning.
While a finding is selected, its named parts retain their normal colors; other
parts use muted gray fills and visible gray outlines, lead-ins, and marks. Selecting
another finding updates the emphasis. Clearing the finding or closing validation
restores normal rendering without changing drawing colors or selection.

Overlaps use the same magenta material shading as **View > Overlap Check**. A
DPI-scaled ring expands and fades continuously while the finding is selected;
both its color and contrasting halo fade as it grows. For overlaps the ring marks the area centroid (possibly between
separate patches); for missing lead-ins it marks the contour start. Rapid warnings
pulse the offending orange dashed segment continuously and mark its contacts with
the completed contour using fixed-screen-size magenta crosshairs with white halos.
Contacts use native lines/arcs and the rapid check's existing numerical tolerances;
shared vertices and tangencies get one marker, and travel along an edge marks the
contact span endpoints. Start-only departure is excluded. Travel entirely inside
a contour has no boundary contact markers. Incomplete findings use the part center when available;
findings without a usable location do not invent a marker. Closing the inspector
clears the highlight and restores the original plate, zoom, and overlap display mode.

Validation does not change placements, programs, lead-ins, or cutting order, save
the nest, or write CNC output. Minimum spacing and plate boundaries are not checked.
It does not verify a post processor's final output. Posting still runs its own
fresh verification and consent flow.

Finish or cancel active nesting/fill operations before validating. The window is
a normal top-level, modeless form. Editing controls and shortcuts stay disabled
while it is open, but the main plate view remains available for wheel zoom,
middle-button pan, and **F** or middle-button double-click to fit. Close the
inspector to resume editing. Cancel, Escape, or closing the window requests
cancellation and waits for the worker to stop before restoring editing controls.
Closing the main window during inspection closes/cancels the inspector first;
close the main window again after inspection has finished.

## Posting workflow

The desktop's **Nest > Post > (post processor)** workflow checks every plate after
post settings are accepted and before asking where to save CNC output. The review
shows all three check categories, even when there are no findings:

- **Overlapping parts:** shared material between placed parts, including containment.
  Holes are subtracted; placing a part inside a sufficiently large cutout is not
  itself an overlap. This uses clean drawing geometry, not added lead-in/out paths.
- **Missing lead-ins:** cutting contours without an actual, nonzero lead-in in the
  placed program. Applying a lead-in to only one contour does not clear the other
  contours. Scribe-only work and scrap cutoff lines do not require lead-ins here.
  The cutting planner supports direct contour piercing without lead-ins; that does
  not suppress this pre-post review warning or grant posting consent.
- **Rapid crossings:** direct XY moves crossing closed, already-cut, untabbed
  contours in cutting order. This includes earlier holes within the same part and
  previously cut parts. A future cut is not an obstacle yet. Actual uncut gaps are
  respected; enabling tabs in settings alone is not evidence that a gap exists.

Findings identify the plate and part's position in the cutting sequence. Read the
scrollable report, cancel to fix the nest, then post again to rerun verification.
Uncheckable geometry is reported as incomplete, not passed. The overlap check reads
clean drawing programs made of the built-in instructions only; a missing instruction
list, any other instruction type, or a hole stored as an absolute-mode subprogram
(OpenNest writes them incremental) makes that part's check incomplete. Multiple interrupted
cut fragments, or a lead-out after an open contour that might cut through a tab,
also require manual review rather than being assumed retained.

## Explicit override

With any warning, **Post Anyway** is disabled until the user selects:

> I understand the listed risks, including possible head crashes and machine or
> material damage. I choose to bypass these warnings and continue posting this nest.

Consent applies only to that posting attempt. Unchecking disables posting again;
opening another review always starts unchecked. Cancel, Escape, and the window's
close button do not write CNC files. Cancel is the default button. A clear report
still requires **Continue Posting**. An unexpected verification failure blocks
posting rather than allowing an override of an absent report.

The editor is modal during verification and posting dialogs. Posting is refused
while auto-nesting, interactive fill, or a busy plate action can still change the
nest. Cancellation keeps the modal dialog open until its worker has stopped.
No automatic repair, resequencing, lead-in insertion, or tab insertion is performed.

## Console

`--post` prints the same report. Warnings prevent CNC output (including overwriting
an existing file) and return exit code 1. After reviewing them, explicitly pass
`--acknowledge-post-risks` to accept the risks for that invocation. The switch does
not skip verification and is not persisted. When `--post` is requested, verification
must pass or be acknowledged before either nest saving or CNC writing. Nest-save
and CNC destinations must differ; collisions are refused even with acknowledgment.
Without `--post`, ordinary nest saving is unchanged; `--no-save` skips that save.

The raw `IPostProcessor` plugin interface remains a low-level writer. Third-party
callers must apply their own review/consent flow using `PostVerificationAnalyzer`;
the gate is installed at OpenNest's desktop and console posting entry points.

## Selected post and cut order

Cincinnati CI Fiber preserves the placed part/contour order and pierce positions
used by this check. The older Cincinnati CL post sorts parts and moves cutoffs;
Gravograph builds and optimizes separate tool passes. Those two posts, and unknown
plugins, therefore show an additional **incomplete final rapid sequence** warning
requiring acknowledgment even if the nest-level checks have no findings. This
change does not silently alter their existing CNC output order.

## Limits and maintainer contract

These checks are warnings, not a machine safety certification. They inspect the
nest's placed programs and direct XY travel, not a simulation of final NC output.
A post processor or controller may change routing, cutting order, lead-ins,
retract height, or parking moves. The checks do not model tipping, slats, clamps,
actual tab strength, kerf, or safe Z height. Review the generated CNC program and
machine setup before cutting, even when this report has no warnings.

`OpenNest.Core/Diagnostics/PostVerificationAnalyzer` owns the cross-platform logic;
its report exposes findings, display text, and `CanPost(risksAcknowledged)`. Use
`AnalyzeForPost` at posting entry points so unknown post ordering is not silently
certified. `IPostVerificationSupport.PreservesPlacedProgramOrder` is an opt-in
contract, not a machine-safety claim; only declare it after verifying the writer's
part order, contour order, and pierce positions. The WinForms dialog renders the
report and enforces per-attempt consent. New callers
must keep inputs stable until analysis completes, honor cancellation, and never
treat incomplete analysis as a clear result. Keep analysis out of paint handlers.
The overlap diagnostic's documented numeric/tessellation limits also apply.

Future hardening should inspect a shared post-specific emitted motion stream,
including controller retracts and final parking, rather than pretending direct XY
geometry proves physical head clearance. The [fixed-program route foundation](cutting-planner.md)
reuses these motion/completion checks but is not yet a desktop planner or an Apply
API; its route-only `Ready` result does not replace fresh posting review.

## Verification on Windows

The core/console tests run cross-platform. Dialog tests and actual desktop behavior
require Windows; Linux cross-compilation is not runtime verification.

1. Run `dotnet test OpenNest.WinForms.Tests/OpenNest.WinForms.Tests.csproj`.
2. Post a nest containing two overlapping parts and a part without lead-ins.
   Verify the report lists the plates/parts, shows all check categories, and disables
   **Post Anyway** until consent is checked. Uncheck it to verify disabling again.
3. Cancel with the button, Escape, and X on separate attempts; none should open the
   output save dialog. Reopen the review and confirm consent is reset.
4. Use a sequence that cuts a closed untabbed part, moves to its far side, then
   rapids back across it. Verify a crossing warning. Change the sequence so the
   perimeter has not yet been cut, then assign a real tab gap and recheck the
   appropriate control cases. Include a hole crossed later in the same part.
5. Acknowledge the warnings and post through both a single-file and multi-file post.
   Confirm output and normal overwrite prompts. Post a clear, leaded nest with Cincinnati CI Fiber and
   verify the report still appears without requiring a risk override.
6. During a large verification, cancel; the editor must stay disabled until the
   worker exits, with no output. A fill still finishing after its progress dialog
   closes must prevent posting until it has completed.

For failures, record the menu action, nest fixture, selected post, visible report,
and exact exception text.

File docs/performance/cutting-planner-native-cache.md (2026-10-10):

# Cutting-planner native curve reuse

The opt-in 144-part synthetic grid probe measures only `CuttingPlanService.Plan`, not build,
fixture creation, assertions, desktop rendering or posting:

```sh
OPENNEST_RUN_CUTTING_PERF=1 dotnet test OpenNest.Tests/OpenNest.Tests.csproj -c Release \
  --filter 'FullyQualifiedName~ReorderSearchTests.DenseGrid144_PerformanceProbe' \
  --logger 'console;verbosity=detailed'
```

Run separate fresh processes on the same machine with build and filesystem caches warm;
there is no in-process plan/JIT warmup, so these are first-call measurements. Compare
`Cutting144 elapsedMs`, `expansions`, `status` and `executionSha256`. The hash covers
expanded owned motions (including called hole programs), their layers, rapid flags,
exact coordinate bits, curve type and arc/circle parameters in source order; it does
not claim byte-identical authored G-code flags or post output. The test also requires
a Ready, independently replayed result and exact source-part conservation. Without
the environment flag it skips. Timing is diagnostic, not a deadline assertion.

The native curve wrapper now lazily owns one private native `Entity` for repeated
contact/containment queries. `ToEntity()` still makes a fresh object for other callers.
No lead or rapid check is skipped: long-lead/tiny-circle numerical contacts make a
fixed-extent material prefilter unsafe. Retest the cutting-planner and native-contact
regressions, especially near tangencies, repeated/concurrent queries and incomplete
material; do not infer posted NC or machine acceptance from this probe.

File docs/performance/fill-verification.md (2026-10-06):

# Fill performance verification

Opt-in synthetic measurements (`OpenNest.Tests/Fill/FillPerformanceTests.cs`):

```bash
OPENNEST_RUN_FILL_PERF=1 dotnet test OpenNest.Tests/OpenNest.Tests.csproj -c Release \
  --filter 'Category=FillPerformance' --logger 'console;verbosity=detailed'
```

Only the exact value `1` enables these tests; otherwise they skip. In PowerShell, set `$env:OPENNEST_RUN_FILL_PERF = '1'` before the same `dotnet test` command, then run `Remove-Item Env:OPENNEST_RUN_FILL_PERF` afterward.

The category covers comparer, group-pattern, rotated-pattern, extents-column, feature-extraction, no-model angle, and FillLinear offset-geometry workloads; individual filters match benchmark method names in `FillPerformanceTests.cs`. Overlap checks are measured separately by `OverlapCheck_ReportsPolygonPairsAndGridChecks` in `OpenNest.Tests/Fill/OverlapCheckPerformanceTests.cs` (same category). Keep harness, inputs, warmups and batches identical before/after; exclude setup/assertions from timing. Comparer/extents allocations are synchronous and current-thread only; parallel group fills omit allocation totals. No timing CI gates or whole-job speedup claims. Keep raw results and run-specific reports outside source control; this guide documents the reusable verification procedure.

### Quantity-limited private fills

Irregular's private block proposals opt into quantity-limited Row/Column stripe fills.
`FillLinear.MaxParts` is a soft row limit: the first primary row stays complete, and
perpendicular copies stop after reaching the requested count. The final fill still
trims its winner to the exact quantity. Existing overlap fallbacks and block spacing
certification remain active; fallback tiling can exceed the soft limit. Nonpositive
limits remain uncapped. Ordinary Fill-strategy fills and the zero-quantity cutout lattice
keep their full-area behavior.

This can change which private block candidate wins; it is not a promise of identical
Irregular layouts. Verify fulfillment, bounds, spacing and rotation policy through
the full pipeline, rather than treating a faster cancelled run as acceptance.

```sh
dotnet test OpenNest.Tests/OpenNest.Tests.csproj -c Release \
  --filter 'FullyQualifiedName~FillLinearMaxPartsTests|FullyQualifiedName~StripeFillerTests|FullyQualifiedName~EngineRefactorSmokeTests'
dotnet test OpenNest.Engine.Tests/OpenNest.Engine.Tests.csproj -c Release \
  --filter 'FullyQualifiedName~IrregularBlockTests|FullyQualifiedName~CutoutLatticeFillTests'
python3 scripts/check-synthetic-nests.py
```

For a supplied slow job, retain a bounded before/after trace, rebuilt probe and input
hashes, and a completion run with all demand placed and zero independent validation
violations. Bound cancellation and the outer process watchdog separately. Do not
extend a known unchanged timeout just to obtain a baseline duration.

### FillLinear unchanged-row validation baseline

```bash
# Both configurations must characterize unchanged production; unset perf flag skips.
dotnet test OpenNest.Tests/OpenNest.Tests.csproj -c Debug \
  --filter 'FullyQualifiedName~FillLinearValidation' --logger 'trx;LogFileName=linear-validation-debug.trx'
dotnet test OpenNest.Tests/OpenNest.Tests.csproj -c Release \
  --filter 'FullyQualifiedName~FillLinearValidation' --logger 'trx;LogFileName=linear-validation-release.trx'
OPENNEST_RUN_FILL_PERF=1 dotnet test OpenNest.Tests/OpenNest.Tests.csproj -c Release \
  --filter 'FullyQualifiedName~FillLinearValidation_ReportsStripeAndControls' \
  --logger 'console;verbosity=detailed' --logger 'trx;LogFileName=linear-validation-perf.trx'
```

`FillLinearValidationPerformanceTests.cs` is self-contained against base APIs: byte-copy and hash the same file in both trees. It times complete production `Fill` calls (not frozen code or overlap-only helpers): horizontal/vertical stripes, full grid, partial-only additions, and single-seed stripe. The closed concave fixture gives counts **8 / 19 / 36 / 29 / 8**; grid is row 8 + 28 additions, partial-only is row 19 + 10 (no full row). Two 100-call warmups and seven 200-call batches per mode alternate forward/reverse mode order. Retain every raw tick/time/current-thread allocation row, including warmups; setup/assertions/output are excluded, count/last-result consumption is identical. No timing or reduced-work assertions belong in this baseline harness.

`PreStep3FillLinear.cs` freezes production `FillLinear` at **1b23ad79f25d77fdd745bfea029de9dff2a91f6d**, separately from the older `LegacyFillLinear`. Reverse only the documented type/constructor rename, namespace/visibility/import additions, nullable directive and import formatting; retain a zero-diff comparison against `git show <base>:OpenNest.Engine/Fill/FillLinear.cs` and SHA-256 hashes. Do not refactor the oracle or use it for before timings. `FillLinearValidationReuseTests` compares ordered IEEE-754 poses/bounds, CNC values/program sharing, drawing references and immutable inputs through both public `Fill` overloads, including concurrent calls on one filler. Valid fixtures assert closed positive-area material and no overlap. The separate invalid overlapping-seed case intentionally remains invalid; in Debug its listener confirms Step1 and Step2 fallback pair `(0,1)` with six parts at each step (zero perpendicular additions). It makes no claim that bbox fallback repairs the seeds.

Keep validation-work counter assertions Debug-only in `FillCacheCollection`, reset counters in `finally`, and retain the invalid fallback and single-seed/partial-only controls. Since the S1 guard shipped (re-delivered 2026-09-30 on `dbcf7de`), `UnchangedRow_ReducesStep2OverlapWork` asserts the reduced Step 2 work (horizontal stripe 8→4 exact / 4→2 preparations / 16→8 triangulations; vertical stripe 36→18 / 4→2 / 38→19) and `GuardedControls_KeepEagerStep2Work` plus `PerpOnly_KeepsPerpOnlyCheckWork` assert single-seed (7/1/8), Horizontal full-grid (36/4/44, matching the 2026-09-27 table), partial-only (36/4/38) and PerpOnly exact-call (H=9/V=3) work stay at base on the current tree. The work-count methods compile entirely within DEBUG — Release counter properties read zero, and empty passing shells would misreport coverage. The invalid fallback control additionally pins production's exact-call total at 2 so a wrongly skipped Step 2 check cannot hide behind a layout match. Whole-job exact preservation needs a separately repeated serial oracle (fresh process, `DOTNET_PROCESSOR_COUNT=1`, verified one-worker thread-pool cap, solve on that worker); ordinary parallel layouts can differ on the same tree, and the serial gate does not replace concurrent differential tests.

Debug behavior/skipped-work checks:

```bash
dotnet test OpenNest.Tests/OpenNest.Tests.csproj -c Debug \
  --filter 'FullyQualifiedName~DefaultFillComparerWorkTests|FullyQualifiedName~FillHelpersTests|FullyQualifiedName~FillExtentsTests|FullyQualifiedName~StrategyOverlapTests|FullyQualifiedName~FillLinearGeometryReuseTests|FullyQualifiedName~CollisionOverlapOnlyTests|FullyQualifiedName~PartOverlapCheckerTests'
```

`PerfCounters.FillScoreComputations`, `PartBoundaryPreparations`, `PartBoundsUpdates`, `OffsetPerimeterEntities`, `FeatureBitmaskCells`, `CrossingPointScans`, `OverlapPolygonPreparations`, and `PolygonTriangulations` increments compile away in Release: zero Release counters prove nothing. `OverlapPolygonPreparations` counts overlap-preparation starts (material extraction), not completed polygons: `Part.Intersects` counts both parts on every call, `PartOverlapChecker` counts once per distinct `Program`. `PolygonTriangulations` counts `Collision` triangulations; the checker triangulates a part at most once per check, and only after a bounding-box hit. Serialize counter assertions in `FillCacheCollection` and reset in `finally`. Keep `OpenNest.Tests/Fill/LegacyFillExtents.cs`, `OpenNest.Tests/Fill/LegacyFillLinear.cs`, `OpenNest.Tests/Geometry/LegacyCollision.cs`, and `OpenNest.Tests/Fill/LegacyPartOverlap.cs` frozen for differential tests (never route them through production helpers), not production or before timings; measure the actual baseline production code.

Predictor regression checks: `dotnet test OpenNest.Tests/OpenNest.Tests.csproj -c Release --filter "FullyQualifiedName~AngleCandidateBuilderTests|FullyQualifiedName~AnglePredictorTests|FullyQualifiedName~FeatureExtractorTests"` (repeat in Debug for bitmap counters). `IrregularAngles_ReportsWarmNoModelPath` measures the public builder with a missing model and skips when a model is installed; never remove real model files to benchmark. `FeatureExtraction_ReportsFullAndScalarOnly` measures extraction separately.

Predictor availability uses the same one-attempt session initialization as inference. Publish completion only after assignment or definitive failure; concurrent callers must wait for the outcome. The builder skips extraction when unavailable and requests scalar-only features when available. Tests use isolated loaders/prediction doubles, not evidence of real ONNX inference.

Whole-job before/after comparisons use `OpenNest.Benchmark` with a `*.manifest.json` corpus and `--parallel 1`. Retain input hashes, exact commands, raw results, validity, fulfillment and cost for both revisions outside source control. Record baseline failures rather than treating them as regressions or tuning the corpus around them; overlapping timing ranges are inconclusive, not proof of unchanged performance.

## Entity identity and hot-test configuration

Use `-c Release` for routine cross-platform test runs, matching CI. Continue running counter-based regressions explicitly in Debug; do not treat fewer Release test cases as lost coverage without checking the DEBUG-only methods and individual skipped outcomes.

Entity IDs are opaque persistence keys, not security tokens or layout ordering keys. New entities use one process-random GUID prefix and an interlocked 48-bit sequence; clones receive fresh IDs. The sequence uses little-endian bytes independent of host byte order and throws on exhaustion rather than wrapping. Explicit restored/imported IDs remain authoritative, including suppressed source-entity IDs. `EntityIdentityTests` covers mixed entity types, concurrent creation, clone identity, serialization and the real `.nest` writer/reader.

For an identity-generation performance change, retain an untouched before tree, use identical harness bytes for both trees and compare full serialized `NestJobResult` SHA-256 hashes for deterministic, mixed curved/concave and zero-spacing jobs. Independently require zero layout violations. Verify each tree repeats its own hashes before using before/after equality as an oracle. If parallel output is unstable, use fresh processes with `DOTNET_PROCESSOR_COUNT=1`, verify a one-worker thread-pool cap and solve on that worker; this serial gate does not replace concurrent identity regressions. Measure solve time separately from validation and output serialization, interleave before/after processes and retain every batch. Re-profile the Release deterministic job to confirm per-entity `Guid.NewGuid` work is removed before claiming the measured gain.

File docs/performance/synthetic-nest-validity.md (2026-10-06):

# Small synthetic-nest validity gate

From the repository root, with .NET 8 and Python 3.9 or later:

```sh
python3 scripts/check-synthetic-nests.py
```

The runner builds the existing `OpenNest.Benchmark` in Release and invokes it with
`--engines Irregular --parallel 2 --progress`. It prints the evidence directory;
`build.log`, `benchmark.log`, `results.csv` and (only on success) `accepted.json`
are retained there. Use `--output <directory>` to choose a durable location.
Progress is written to `benchmark.log`, not streamed to the terminal.

The entire build + benchmark has a 300-second watchdog. Nonzero subprocess exits,
cancellation and timeout fail the gate. On Unix the runner kills its owned process
session, including descendants; Windows uses `taskkill /T /F`. Build servers are
disabled for this check. `--timeout <seconds>` may shorten, never extend, the budget.
Default concurrency is two; `--parallel 1` is serial and `--parallel 4` is the upper
bound for a machine with adequate resources. Do not use the override to oversubscribe
CI or a busy host.

## The six committed fixtures

These are wholly synthetic, generated from CNC polylines through `Drawing`, `Nest`
and `NestWriter`. No drawing archives or customer jobs are involved. All use inches,
quadrant 1, part spacing 0.25, edge spacing 0.25 on every side, and no salvage credit.
Sheet dimensions below are X length by Y width (the `Size` API takes width first).

| File stem | Synthetic demand | Sheet X × Y | Expected sheets |
| --- | --- | --- | --- |
| `single-triangle` | one 6 × 5 triangle | 20 × 20 | 1 |
| `paired-wedges` | two wedges, vertices (0,0), (8,0), (6,20), (0,20) | 30 × 15 | 1 |
| `repeated-ell-fill` | seven 9 × 7 L shapes, arm thickness 3 | 60 × 40 | 1 |
| `mixed-irregular` | one triangle, two L shapes, three pentagons | 30 × 25 | 1 |
| `rotation-edge-fit` | one 8 × 3 rectangle that must turn to fit | 3.52 × 8.52 | 1 |
| `multi-sheet` | three 8 × 8 squares, only one fits each sheet | 10 × 10 | 3 |

All drawings permit automatic rotation. The edge-fit fixture deliberately leaves
0.02 extra work-area room: it is a tight rotated fit, not an exact-contact test.
The qty-two fixture checks one-sheet interlocking fulfillment; the qty-greater-than-two
fixture exercises a job eligible for Fill-block candidates. This smoke gate does not
assert which internal candidate won; the existing pair/block unit tests retain those
contracts. These are ordinary solid contours, not acceptance of future hole nesting,
containment sequencing or shop-use safety.

To regenerate the six archives through the repository's IO APIs:

```sh
dotnet run --project test-data/synthetic-nests/Generator/Generator.csproj -- test-data/synthetic-nests
```

The generator fixes dates/ZIP timestamps and leaves customer, maker and source-path
metadata empty. Inspect the generated diff before committing. It never reads external
DXFs. Fixtures contain demand and plate defaults, not prepacked layouts.

## Fail-closed result checking

The runner requires exactly the six expected input files, known positive demand and
exactly one Irregular result for each. `Baseline` rows are ignored, not accepted as
engine results. Unknown engines/jobs, duplicates, missing results, empty output,
invalid layouts, crashes, timeout notes, incomplete fulfillment, changed inputs and
unexpected sheet counts all fail. Benchmark's exit code zero alone is not acceptance.
CSV flags must be the exact emitted `True`/`False` values; placed/requested demand
must match the fixture contract. A saved CSV can be checked without solving:

```sh
python3 scripts/check-synthetic-nests.py --check-csv <results.csv>
python3 scripts/test_check_synthetic_nests.py -v
```

The unit checks use labeled synthetic CSV rows and a real watchdog process-tree
probe. The end-to-end command uses actual benchmark results and the production
independent layout validator. This gate supplements, never replaces, the existing
geometry, contract, cancellation, sequencing, posting and cross-platform unit suites.
GitHub's cross-platform workflow runs both the checker tests and the six-fixture gate
in a separate job, concurrently with four independent unit-suite jobs (main, Engine,
IO and Server). Unit jobs retain the default Debug configuration and do not cancel
siblings on failure. The final `tests` check requires the entire unit matrix and
synthetic job to succeed; failed, cancelled or skipped dependencies cannot produce
a green final check. This preserves the existing check name without changing branch
protection or removing tests. `python3 scripts/test_ci_results.py -v` exercises the
same fail-closed aggregate command used by CI. The six-minute step limit and
`--parallel 2` synthetic-runner limit are unchanged.

This fan-out removes inter-suite serialization, not individual geometry-test work.
It uses additional independent runners and repeats restore/build setup; actual wall
time depends on the slowest job and runner queueing. It is not a CPU speed claim or
a reason to skip correctness fixtures. Windows runtime acceptance is separate; a
Linux pass does not certify Windows tree termination or desktop/shop interactions.

## Validity is not speed

Parallel elapsed times are diagnostic only. Serial and parallel runs must account for
the same fixtures and fulfill the same demands; they do not promise identical poses.
Even `--parallel 1` here is a smoke gate, not a controlled performance comparison.
Actual speed claims need serial quiet, interleaved comparisons with frozen inputs and
source provenance. Full customer-corpus audits remain opt-in and uncommitted.

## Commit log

2026-04-06 fix: add bend detection and etch lines to BOM import path
    BOM import was skipping BendDetectorRegistry.AutoDetect and
    Bend.UpdateEtchEntities, so parts imported via BOM had no etch
    or bend lines. Now matches the CadConverterForm import behavior.
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2026-04-06 fix: allow large parts to use remnant space on existing plates
    Previously, parts classified as "Large" skipped all existing plates
    and always created new ones. This caused one-unique-part-per-plate
    behavior since most parts exceed half the plate dimension. Now large
    parts search viable remnants on existing plates before creating new
    ones, matching the intended part-first behavior.
2026-04-06 fix: consolidation pass packs medium/small parts onto shared plates
    After the main single-pass placement, leftover items are now packed
    together using the engine's multi-item Nest()/PackArea() methods
    instead of creating one plate per drawing. First tries packing into
    remaining space on existing plates, then creates shared plates for
    anything still remaining.
2026-04-06 fix: defer small parts to consolidation pass for shared plates
    Small parts no longer create their own plates during the main pass.
    Instead they're deferred to the consolidation pass which fills them
    into remaining space on existing plates, packing multiple drawing
    types together. Drops from 9 plates to 4 on the test nest file.
2026-04-06 fix: recalculate remnants after each fill to prevent overlaps
    The consolidation pass was iterating stale remnant lists after placing
    parts, causing overlapping placements. Now recalculates remnants from
    the plate after each fill operation. Also added plate options to the
    real nest file integration test.
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2026-04-06 fix: consolidate tail plates by upgrading instead of creating new plates
    Three fixes to TryUpgradeOrNewPlate and a new post-pass:
    1. Change ShouldUpgrade from < to <= so upgrade wins when costs are
    tied (e.g., all zero) — previously 0 < 0 was always false
    2. Guard against "upgrades" that shrink a dimension — when options are
    sorted by cost and costs are equal, the next option may have a
    smaller length despite higher width (e.g., 72x96 after 60x144)
    3. Revert plate size when upgrade fill fails — the plate was being
    resized before confirming parts fit, leaving it at the wrong size
    4. Add TryConsolidateTailPlates post-pass: after all nesting, find the
    lowest-utilization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
2026-04-07 fix: re-enable delete plate button when changing plate selection
    UpdateRemovePlateButton() was only called from PlateListChanged,
    not CurrentPlateChanged, so the button stayed disabled after switching
    away from the sentinel plate.
2026-04-07 fix: check longest side against plate dimensions in best fit filter
    The filter only checked ShortestSide against the plate's short dimension,
    allowing results where the long side far exceeded the plate length.
2026-04-07 refactor: clean up MultiPlateNester code smells and duplication
    Extract shared patterns into reusable helpers: FitsBounds (fits-normal/
    rotated check), OptionWorkArea (edge-spacing subtraction), DecrementQuantity,
    TryWithUpgradedSize (upgrade-try-revert), FindSmallestFittingOption.
    Add PlateResult.AddParts to consolidate dual parts-list bookkeeping.
    Cache sorted plate options and add HasPlateOptions property. Introduce
    MultiPlateNestOptions to replace 10-parameter Nest signature with a
    clean options object. Fix fragile Drawing.Name matching with reference
    equality in PackIntoExistingRemnants.
2026-04-07 perf: use actual geometry instead of tessellated polygons for push distance
    - Add entity-based DirectionalDistance overload to SpatialQuery that
    uses RayArcDistance/RayCircleDistance instead of tessellating arcs
    and circles into line segments
    - Add GetOffsetPartEntities, GetPerimeterEntities, GetPartEntities to
    PartGeometry for non-tessellated entity extraction
    - Update Compactor.Push to use native entities instead of tessellated
    lines — 952 circles = 952 entities vs ~47,600 line segments
    - Use bounding box containment check to skip cutout entities when no
    obstacle is inside the moving part (perimeter-only for common case)
    - Obstacles always use perimeter-only entities since cuto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
2026-04-07 fix: guard against null actionManager during PlateView construction
    Plate setter is called in the constructor before actionManager is
    initialized, causing a NullReferenceException on startup.
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2026-04-07 feat: improve multi-plate nesting with multi-remnant filling and better zone scoring
    - Iterate all remnants instead of only the first when packing and filling
    - Improve ScoreZone with estimated part count and aspect ratio matching
    - Cache bounding boxes in SortItems and remnants in TryPlaceOnExistingPlates
    - Make TryConsolidateTailPlates loop until stable, trying all donor/target pairs
    - Fix consolidation grouping to use BaseDrawing reference instead of name
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2026-04-08 fix: increase max zoom and handle GDI+ thread race in PlateView
    Raise ViewScaleMax from 3000 to 10000 for deeper zoom. Catch
    InvalidOperationException in hoverTimer_Elapsed when GraphicsPath is
    concurrently used by the paint thread.
2026-04-08 fix: correct compactor circle-to-circle directional distance
    The vertex-to-entity approach in DirectionalDistance only sampled 4
    cardinal points per circle, missing the true closest contact when
    circles are offset diagonally from the push direction. This caused
    the distance to be overestimated, pushing circles too far and
    creating overlap that worsened with distance from center.
    Add a curve-to-curve pass that computes exact contact distance by
    treating the problem as a ray from one center to an expanded circle
    (radius = r1 + r2) at the other center. Includes arc angular range
    validation for arc-to-arc and arc-to-circle cases.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
2026-04-08 feat: add Edit Drawings in Converter button to reopen nest drawings in CadConverterForm
    Adds a toolbar button on the Drawings tab that opens the CAD converter
    pre-populated with the current nest drawings, allowing users to revisit
    layer filtering, quantities, and other settings without re-importing.
    Also fixes PlateView stealing focus from text inputs on mouse enter
    and FilterPanel crashing when loaded before form handle is created.
2026-04-08 fix: preserve suppression state when reopening converter
    LoadItem was resetting all entity visibility to true, overriding the
    suppression state set by LoadDrawings. Now stores suppressed entity IDs
    on FileListItem and re-applies after the reset. Also auto-unchecks
    layers where all entities are suppressed, and syncs suppression state
    back to the FileListItem when filters change.
2026-04-08 fix: respect suppression state in filter panel and guard DetermineWinding
    FilterPanel.LoadItem was hardcoding all layer and line type checkboxes
    to checked, ignoring actual visibility state. Now reads Layer.IsVisible
    and entity IsVisible to set correct checked state.
    Also guard DetermineWinding against shapes with fewer than 3 polygon
    points (defaults to CCW) to prevent crash when applying lead-ins.
2026-04-08 fix: show cutting parameters dialog before assigning lead-ins
    Auto-assign lead-ins silently reused existing plate parameters with no
    way to change them after the first assignment. Now a dialog with the
    full CuttingPanel is shown every time, pre-populated with the current
    settings, so the user can review and modify before confirming.
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2026-04-09 fix: marshal timer callbacks to UI thread to prevent GDI+ threading exception
    System.Timers.Timer fires on thread pool threads, causing GraphicsPath
    objects to be accessed concurrently by hover detection and OnPaint,
    triggering "Object is currently in use elsewhere" in DrawParts.
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2026-04-09 feat: add option to round lead-in angles for circle holes
    Snaps lead-in angles on ArcCircle contours to a configurable
    increment (default 5°), reducing unique hole variations from
    infinite to 72 max. Rounding happens upstream in EmitContour
    so the PlateView and post output stay in sync.
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2026-04-09 fix: apply SubProgramCall offset additively and restore curpos after expansion
    ConvertMode.ToIncremental skips SubProgramCalls when computing deltas,
    so all code paths that expand SubProgramCalls must: (1) set curpos to
    savedPos + Offset before expanding, and (2) restore curpos afterward
    so subsequent incremental codes get correct deltas.
    Fixed in ConvertProgram, GraphicsHelper (AddProgram, AddProgramSplit),
    PlateRenderer (DrawRapids, DrawProgramPiercePoints, GetFirstPiercePoint),
    and CutDirectionArrows.
2026-04-09 fix: draw rapid move to hole center before sub-program lead-in
    The rapid from the previous feature to the hole center is implied by
    the SubProgramCall offset but wasn't being drawn. Now DrawRapids
    renders this traverse before recursing into the sub-program.
2026-04-09 fix: let DrawRapids track actual tool position through sub-programs
    Don't restore pos after SubProgramCall expansion in DrawRapids — the
    machine moves from hole to hole sequentially, so rapids should connect
    from the previous hole's end to the next hole's center.
2026-04-10 fix: track tool position through sub-programs in ConvertMode
    ConvertMode.ToIncremental skipped SubProgramCall codes entirely when
    computing deltas, so parent motions after a sub-call were encoded as if
    the tool never moved. Several traversal sites (ConvertProgram,
    GraphicsHelper, PlateRenderer, CutDirectionArrows, Program.BoundingBox)
    worked around this with save/restore hacks that treated sub-calls as
    transparent — but DrawRapids legitimately tracks actual tool position,
    so after the last hole the first perimeter rapid was applied to the
    wrong base, drifting the rendered perimeter past the plate edge by
    roughly the distance to the last hole.
    Fix the root cause: ToIncremental and ToAbsolu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
2026-04-10 fix: draw sub-program rapid directly to lead-in pierce
    The SubProgramCall branch in DrawRapids used to draw a rapid from the
    previous feature's end to the hole center, then rely on the sub-program's
    own first rapid to draw from center to the lead-in pierce. That rendered
    a phantom center-hop segment that doesn't exist physically — a
    SubProgramCall is a coordinate-frame shift (emitted as a G52 bracket on
    Cincinnati), not a move to the hole center.
    Look ahead through the sub-program for its first pierce point in
    absolute coordinates and draw a single direct rapid from pos to that
    pierce. Recurse into the sub with skipFirstRapid: true so the sub's
    first rapid isn't drawn again on top.
    Co-Au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
2026-04-10 fix: emit G52 bracket for hole sub-program calls
    CincinnatiSheetWriter.WriteHoleSubprogramCall emitted
    `M98 P<num> X<x> Y<y>`, but per manual §3.98 ("M98 SUB-PROGRAM CALL
    WITH NO ARGUMENTS") M98 takes only P and L — the X/Y had no defined
    meaning to the control. The intent was to position the sub-program at
    the hole center, which is what G52 is for per §1.52 ("local work
    coordinate system") and which explicitly does not move the nozzle.
    Emit the documented G52 bracket instead:
    G52 X<hole.x> Y<hole.y>
    M98 P<holeSubNum>
    G52 X0 Y0
    The hole sub-program is authored in hole-local coordinates, so its
    first rapid (the lead-in to the pierce point) resolves to the absolute
    pierce under the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
2026-04-10 fix: show both offset and rotation in SubProgramCall.ToString
    The either/or format meant a SubProgramCall with both a non-zero
    Offset and non-zero Rotation would only show the Offset, hiding the
    rotation metadata. The data model supports both independently, so the
    display should too.
    Also fixes a zero-field leak where the old fallback emitted
    `G65 P_ R0` for calls with no rotation. Now each field is only shown
    when non-zero, and `G65 P_` with no arguments is emitted when
    neither is set.
    Note: SubProgramCall.ToString is purely a debug/display aid. The
    Cincinnati post emits sub-calls via the G52 + M98 bracket, not via
    G65, so this format doesn't correspond to real machine output.
    Co-Authore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
2026-04-10 feat(ui): add bool checkbox support to ShapeLibraryForm
    BuildParameterControls now creates a CheckBox (wired to UpdatePreview) for bool properties instead of a TextBox; CreateShapeFromInputs reads the Checked value via a short-circuit before the TextBox cast.
2026-04-10 feat(ui): add filtered pipe size dropdown to shape library
    Renders PipeSize as a DropDownList ComboBox, filters entries to those fitting
    the current hole geometry, disables the combo when Blind is checked, and
    appends an invalid-pipe warning to the preview info when TryGetOD fails.
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2026-04-11 feat(shapes): add PlateSizes catalog and wire Ctrl+P to snap-to-standard
    PlateSizes holds standard mill sheet sizes (48x96 through 96x240) and
    exposes Recommend() which snaps small layouts to an increment and
    rounds larger layouts up to the nearest fitting sheet. Plate.SnapToStandardSize
    applies the result while preserving long-axis orientation, and the
    existing Ctrl+P "Resize to Fit" menu in EditNestForm now calls it
    instead of the simple round-up AutoSize.
2026-04-11 fix(splitter): preserve disconnected strips and trim cuts around cutouts
    Splits that cross an interior cutout previously merged physically
    disconnected strips into one drawing and drew cut lines through the hole.
    The region boundary now spans full feature-edge extents (trimmed against
    cutout polygons) and line entities are Liang-Barsky clipped, so multi-split
    edges work. Arcs are properly clipped at region boundaries via iterative
    split-at-intersection so circles that straddle a split contribute to both
    sides. AssemblePieces groups a region's entities into connected closed
    loops and nests holes by bbox-pre-check + vertex-in-polygon containment,
    so one region can emit multiple drawings when a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
    [split_test.dxf]
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2026-04-13 fix(geometry): add Entity.Clone() and stop NormalizeEntities from mutating originals
    ShapeProfile.NormalizeEntities called Shape.Reverse() which flipped arc
    directions on the original entity objects shared with the CAD view. Switching
    to the Program tab and back would leave arcs reversed. Clone entities before
    normalizing so the originals stay untouched.
    Adds abstract Entity.Clone() with implementations on Line, Arc, Circle,
    Polygon, and Shape (deep-clones children). Also adds CloneAll() extension
    and replaces manual duplication in PartGeometry.CopyEntitiesAtLocation and
    ProgramEditorControl.CloneEntity.
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2026-04-14 fix(ui): show Drawings tab before Plates in EditNestForm
    Users need to import a drawing first, so Drawings tab should be the
    default landing tab to reduce steps.
2026-04-15 feat(ui): populate material combobox from post processors
    Replaces the material textbox on EditNestInfoForm with a combobox whose
    items are aggregated from every loaded post processor that implements the
    new IMaterialProvidingPostProcessor interface. CincinnatiPostProcessor
    exposes its configured MaterialLibraries entries. Free-text entry still
    works so custom materials remain usable.
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2026-04-15 fix(cnc): offset SubProgramCall positions in Program.Offset
    Program.Offset only adjusted Motion codes, so subprogram calls kept
    their original offsets after a part was translated. Apply the offset
    to SubProgramCall.Offset too so hole subprograms follow the part.
2026-04-15 feat(cincinnati): emit SubProgramCall features as M98 hole calls
    When a feature is a single SubProgramCall, wrap the call with a G52
    offset shift, emit M98 P<num>, reset G52, and add M47 between features.
    Accepts an optional hole subprogram id map so the post can remap
    drawing-local subprogram ids to machine subprogram numbers.
2026-04-15 refactor(cnc): extract rapid enumeration into RapidEnumerator
    Pulls the rapid-walk logic (sub-program unwrapping, first-pierce lookup,
    incremental-vs-absolute handling, first-rapid skipping) out of
    PlateRenderer.DrawRapids into a reusable RapidEnumerator in Core so it
    can be unit-tested and reused outside the renderer.
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2026-04-16 fix(ui): address code review issues in color scheme feature
    - Sync PlateView.BackColor on repaint so live scheme switch updates background
    - Guard FromHex against truncated hex strings (< 6 chars)
    - Cache disk schemes to avoid re-reading Schemes/ folder on every access
2026-04-16 feat(ui): distinct Dark palette and recolor drawings on scheme switch
    - Replace Dark part colors with high-contrast neon/electric palette
    - Recolor existing drawings in open nests when scheme changes
2026-04-16 fix(cutting): restrict tabs to external perimeter and clarify tab UI
    Tabs were being applied to internal cutouts and circle holes, which is
    incorrect — only the external perimeter should be tabbed. Restructured
    the Tabs panel to use radio buttons ("Tab all parts" vs "Auto-tab by
    smallest dimension") so the two modes are clearly mutually exclusive
    instead of the confusing implicit override behavior.
2026-04-16 feat(shapes): generate unique drawing names from parameters and add toolbar button
    Shape library drawings now get descriptive names based on their
    parameters (e.g. "Rectangle 12x6", "Circle 8 Dia") instead of generic
    type names, preventing silent duplicates in the DrawingCollection
    HashSet. Added a Shape Library button to the Drawings tab toolbar
    and removed separators between toolbar buttons for a cleaner look.
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2026-04-17 refactor(fill): use native entity geometry for linear copy distance
    Replaces PartBoundary polygon edges with PartGeometry.GetOffsetPerimeterEntities
    (inflated Line/Arc entities) so arcs are handled exactly without the polygon
    sampling error that previously required a bboxDim + PartSpacing clamp. Adds
    bbox DirectionalGap / PerpendicularOverlap early-outs to skip pair checks
    that can't produce a valid slide, and removes the now-unused PartBoundary
    cache, GetPatternLines/GetOffsetPatternLines helpers, and ComputeCopyDistance
    clamp.
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2026-04-23 fix(io): handle flipped OCS normal on DXF ellipse import
    Ellipses with extrusion direction Z=-1 had their parametric direction
    reversed, causing the curve to appear mirrored. Negate start/end
    parameters when Normal.Z < 0 to correct the minor-axis traversal.
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2026-04-24 fix(core): use chain tolerance for entity gap check to prevent spurious rapids
    Ellipse-to-arc conversion creates tiny floating-point gaps (~0.00002")
    between consecutive arc segments. ShapeBuilder chains these with
    ChainTolerance (0.0001"), but ConvertGeometry checked gaps with Epsilon
    (0.00001"). Gaps between these thresholds generated spurious rapid moves
    that broke GraphicsPath figures, causing diagonal fill artifacts from
    GDI+'s implicit figure closing.
    Root cause fix: align ConvertGeometry's gap check with ShapeBuilder's
    ChainTolerance so precision gaps are absorbed instead of generating rapids.
    Defense-in-depth: GraphicsHelper no longer breaks figures at near-zero
    rapids, protecting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
2026-04-30 feat(ui): render DXF text annotations in CAD converter preview
    Extract MText and TextEntity from the CadDocument during DXF import
    and render them in the EntityView. Handles text alignment (left/center/
    right via InsertPoint vs AlignmentPoint) and replaces AutoCAD control
    codes (%%p → ±, %%d → °, %%c → ⌀). MText formatting codes are
    stripped before display.
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2026-05-08 fix(io): deduplicate circles and full-circle arcs during DXF import
    Duplicate circle entities at the same location inflated pierce counts
    and cut pricing (e.g. SULLYS-035 showed 9 pierces instead of 8).
2026-05-23 fix(ui): remove cut-off preview debounce for immediate cursor tracking
    The 16ms timer delay made the preview feel laggy. Regenerate directly
    on mouse move instead.
2026-05-23 fix(io): remove zero-sweep arcs during DXF import
    DXF files can contain degenerate arcs where start angle equals end angle
    (zero sweep), often left as construction artifacts by CAD software.
    These create spurious shapes in ShapeBuilder — e.g. SULLYS-033.dxf
    showed 5 loops instead of 4 (3 cutouts + perimeter).
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2026-08-07 fix: improve arc-tangency fitting and add layered engrave/cut passes for GravographIS
    GeometrySimplifier/ArcFit now fit arcs that pass exactly through run
    endpoints while balancing tangency error between trusted and estimated
    directions, fixing arcs that previously bulged or broke tangent
    continuity at fillet/compound-curve junctions.
    GravographIS post processor gains per-layer (engrave/cut) tool passes
    via a new GravographISPostConfig, so ENGRAVE/ETCH-tagged geometry runs
    as a separate scribe pass with its own feed/depth and an operator
    pause before the cut pass (spring-floated spindle needs a tool swap).
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2026-09-15 Add OpenNest.Benchmark: generic head-to-head engine comparison harness
    Loads any .nest file (or folder of them) via NestReader and nests every
    drawing with quantity > 0 using each registered NestEngineBase, so it
    works sight-unseen against arbitrary real jobs without any hardcoded
    geometry. Optionally sweeps a fixed --sheet-sizes list instead of each
    file's own plate size.
    - BenchmarkJob/JobLoader build immutable job specs; a fresh Plate and
    NestItem list is created per (job, engine) run so state never leaks
    between engines or jobs.
    - NestValidator rejects a layout if any part falls outside the work
    area, any two parts are closer than PartSpacing (checked via each
    part's own world-s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
2026-09-16 Fix NestValidator: add area-budget backstop, cheaper polygon conversion
    Collision.HasOverlap (and Part.Intersects, which shares the same
    underlying algorithm) was observed to return false negatives on real,
    complex production geometry: a layout with a combined placed area over
    7x the plate's work area passed the polygon-based spacing/overlap
    check with zero flagged pairs. This is a pre-existing gap in
    OpenNest.Core's Collision detection, not something introduced here,
    but it let an obviously-invalid layout score as "valid".
    ValidateAreaBudget adds a hard mathematical backstop that does not
    depend on Collision at all: non-overlapping parts confined to the work
    area can never have a combined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
2026-09-24 feat(astra): add independent nesting engine and fix hole validation
    Replace the Terra scaffold with an independent configuration-space contact placer and bounded stock-plan search. Include plugin tests, synthetic and DXF benchmark drivers, results, and deployment documentation.
    Correct shared collision clipping and hole subtraction so curved-hole inserts validate consistently. Cover translated layouts, spacing violations, operand order, winding, and independent boolean-area comparisons.
    Validation: 1,293 tests passed with 12 fixture skips; all 34 synthetic/generated and four DXF cases are valid and complete.
    [baseline-dxf.csv, baseline-generated.csv, baseline-synthetic.csv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]
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
